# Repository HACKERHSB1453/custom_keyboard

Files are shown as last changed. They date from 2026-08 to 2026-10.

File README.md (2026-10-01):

# my-kkeb

A 113-key modular mechanical keyboard, split into 5 boards that connect with magnetic pogo pins. It is designed in KiCad (PCB) and Fusion (case) for Hack Club's KEEB program.

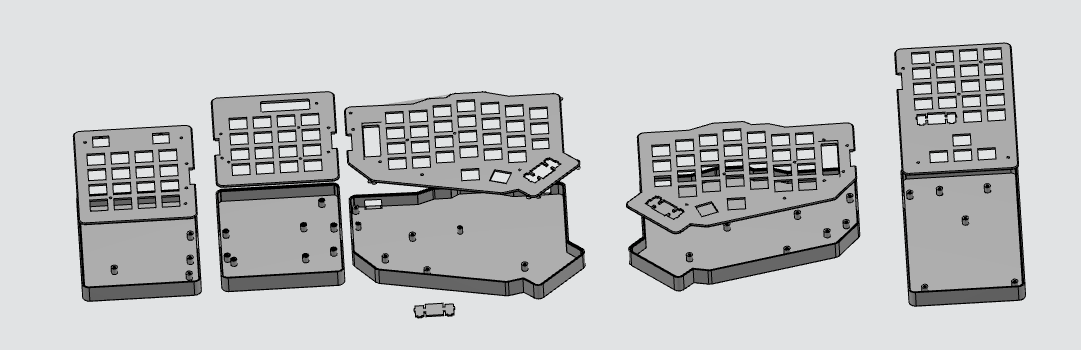
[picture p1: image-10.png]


## Why I built it
I build this because I was interested in split keyboard. I really like how they look but I dont like how they sacrifice a lot of keys and thats makes them difficult to use for some things. So I had the idea to make a modular split keyboard. 
## How it works
The way it works it pretty simple. A pi pico powers it all. I used mcp23017 chips so I could get enough pins for all the matrix rows and colums from just transfering 4 pins thought the modules.
## Repository layout

```
my-kkeb/                 KiCad project (schematics + PCB)
  CUSTOM.pretty/         custom footprints (pogo connector, hot-swap socket, USB-C)
  export/fab/            Gerber zips, one per board, ready for JLCPCB
case/
  <Module>/Case_*.step   case for each module (one body per file for printing)
  <Module>/Plate_*.step  switch plate for each module
  my-kkeb-case-assembly.step   everything together, for viewing only
```

## Building it

1. **PCBs:** upload each zip from `my-kkeb/export/fab/` to JLCPCB as a separate order (5 boards).
2. **Case:** print the `Case_*` and `Plate_*` files from `case/`. I plan to use JLC3DP in black resin.
3. **Parts:** see `bom.csv`
4. **Firmware:** not done yet

## What I learned
I learned a lot of stuff. I learn a lot about how keyboard work. What I think that is the most valuable thing about what I learned is the knowladge about PCBs, I knew some stuff but I have never tried to actually make a PCB before. And it was actually harder than I thought for some things. But overall I enjoyed a lot doing everything. Making the case was definetely harder than doing the PCB, because I didnt really know how to make the it at first. I tried using FreeCad at first since fusion wasnt in linux, and I didnt liked onshape. But I ended up intalling fusion in my windows and Did 95% of they case there and a did some changed on freecad late on.

## Build journal

**Total: 80 hours**

| Date | Hours | What I worked on |
|---|---|---|
| August 3 | 1 h | Research |
| August 4 | – | GitHub repo |
| August 14 | 2 h 50 min | Planning and first 3D model |
| August 15 | 8 h 40 min | Main model, planning, OLED, pogo pins, MCP23017 |
| August 16 | 3 h | PCB |
| August 17 | 3 h 30 min | PCB |
| August 18 | 2 h | Model changes, PCB |
| August 19 | 9 h | Schematic, ERC |
| August 20 | 7 h | PCB placement |
| August 21 | 16 h | PCB placement and wiring |
| August 23 | 4 h | Wiring |
| August 28 | 6 h | Case |
| September 13 | 7 h | Case, rewiring |
| September 20 | 3 h | Case |
| September 25 | 7 h | Case |

### August 3 (1 h)
I have been searching about how keayboards work. And how matrix system works. Spend a total of 1 hour investigating and watching videos about how to keyboards work and how to create one. Here are the links:
- https://www.youtube.com/watch?v=8WXpGTIbxlQ
- https://www.youtube.com/watch?v=7LyziNdFlew
- https://www.youtube.com/watch?v=h-NM1xSSzHQ

### August 4
I created the github repo.

### August 14 (2 h 50 min)
- **2:10AM-3AM:** Planning my keyboard.
- **10PM-12AM:** I kept planning and making a 3D model to get an idea about how the keyboard should look like.

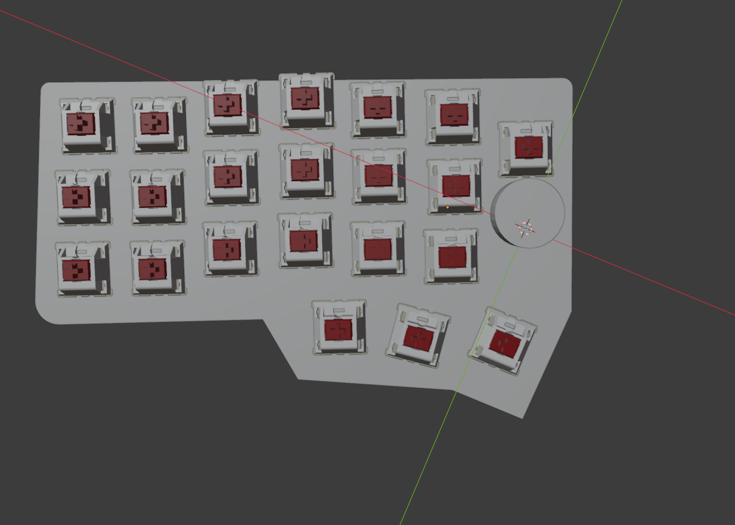
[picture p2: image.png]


### August 15 (8 h 40 min)
- **12AM-3AM:** I finished the main model.

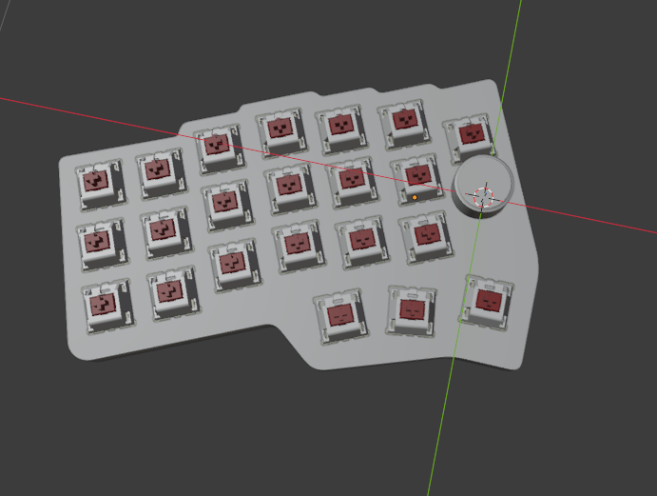
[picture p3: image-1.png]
  
- **3AM-4:40AM:** I tought that I could add more things so I made the keyboard bigger. And also added attachable parts.

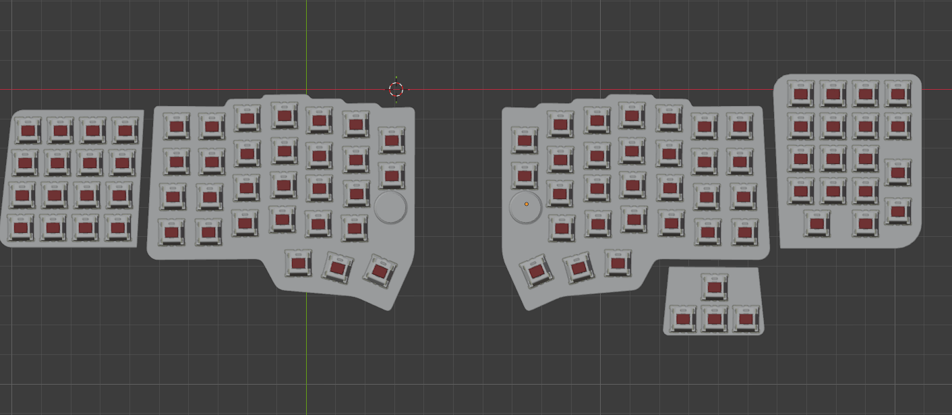
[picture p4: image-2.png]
  
- **4:40AM-6AM:** I planned where everything will go. Searched about how to make the keyboard hotswappable. I had a problem and it is that the keyboard has 96 keys and 2 knobs. The pi pico doesnt have enough pins. I had two main options, use 2 pi picos or use a another chip. But after inverstigating I found ot a way to make it work with a single pi pico.
- **2PM-4PM:** I added an oled screen, installed kicad. And also searched about ways to connect the keyboard with magnets. I found out about pogo pins. And I decided using them.
- **11:20PM-12AM:** I searched about encoreds and searched about how a MCP23017 works and how to use it. I also watched this video about it

### August 16 (3 h)
- **12:20AM-1:50AM:** I created the kicad project and started adding the base thing like the swithes and the pi pico
- **8PM-11PM:** I started designing the pcb.
  - **8:15PM-9PM:** At this point i had the matrix of the right and left part, but it wasnt wired yet.

### August 17 (3 h 30 min)
- **12:30AM-1:40AM:** kept drawing the switch matrix: D30-D58 and their switches
- **3:20AM-3:50AM:** moved the whole matrix out of the main sheet into its own sheet called `left_part` and started using hierarchical schematic since it was for my case. I couldnt find much info online, but I managed to make it work
- **7:30PM-11PM:** I continued with the PCB, I accidentally forgot to save the right part the day before and had to redo that. I also started organizsing thingsa and connect the two main parts. I also search about mousebites. And I decided to use it since the keybaord will be split in multiple parts.

### August 18 (2 h)
- **4AM-4:10AM:** split `left_part` into two sheets, **Left** and **Right** (60 symbols each), and made an empty numpad sheet
- **2:30PM-3:30PM:** I made some changes to the keyboard model.

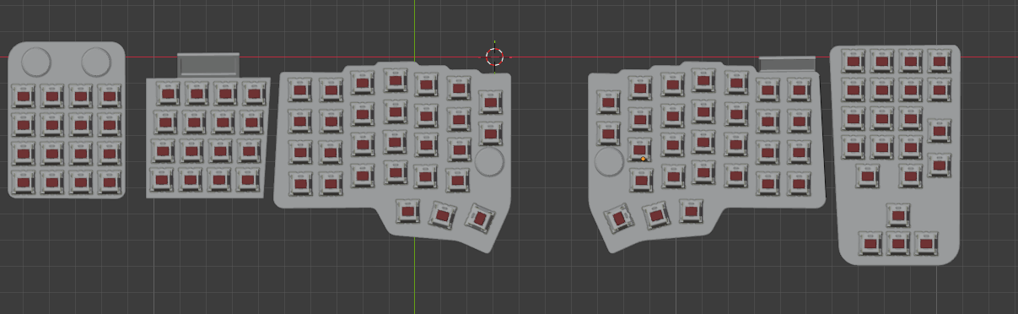
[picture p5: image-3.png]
  
- **3PM-3:50PM:** filled the **Numpad** sheet: switches, diodes D59-D80 and its connector J3. Added SW2 to the Left sheet
- **11PM-12AM:** I continued with the pcb

### August 19 (9 h)
- **12AM-3AM:** I kept doing the pcb, and finished the connections. I tried to use schematic hiererchy to organize it all. I hope I didnt mess it up. In this period I basically added the Macro pad and the git pad. Here are some photos:
  - **12AM-1AM:** made the **Macro_pad** sheet (diodes D81-D96, connectors J5, J7, J8) and an empty Git_pad sheet
  - **2:25AM-3AM:** filled the **Git_pad** sheet (diodes D97-D112, connector J9)

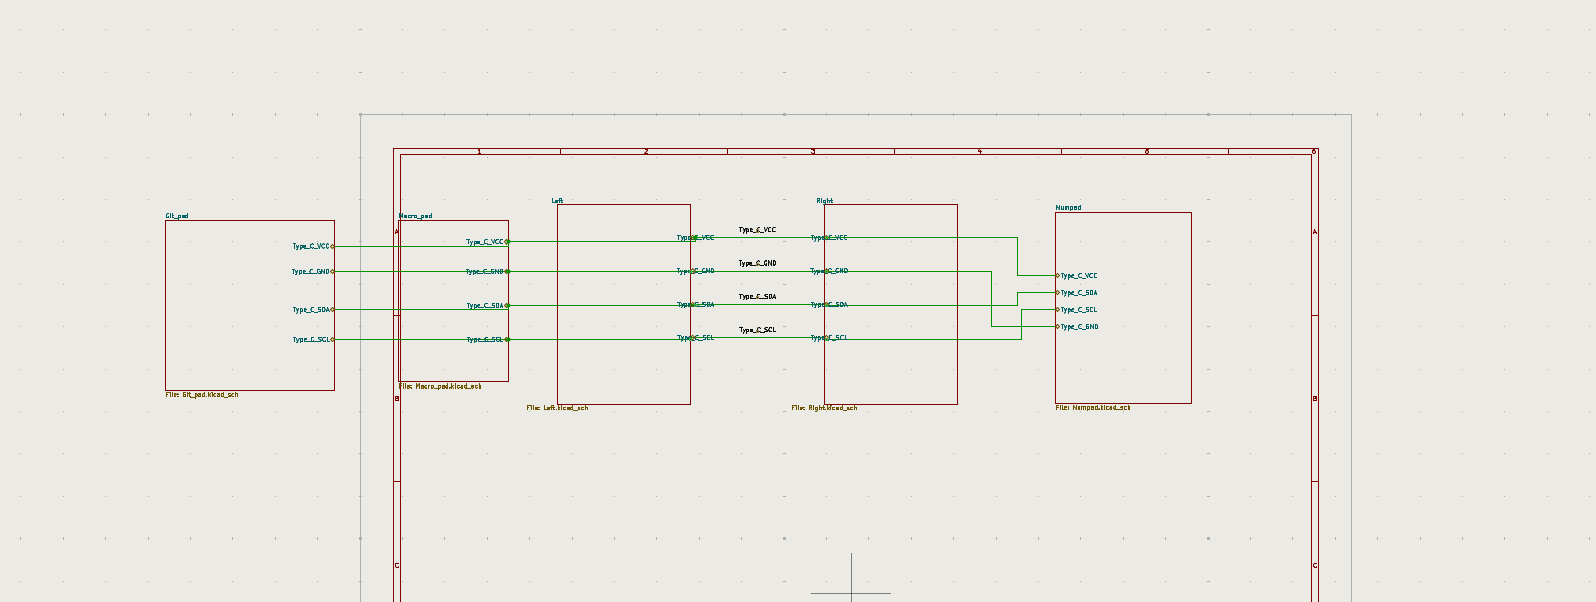
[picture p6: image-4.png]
  
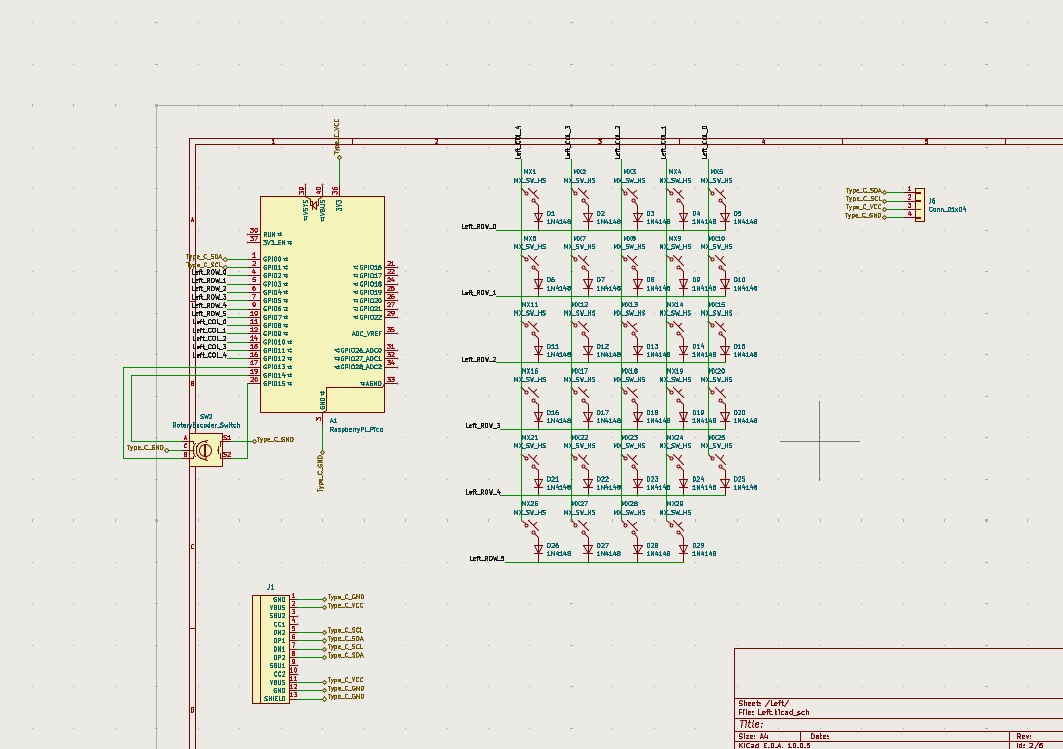
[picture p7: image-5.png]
  
- **3AM-7AM:** I fixed all the errors that didnt let me start the design of the PCB
  - **4:45AM-6:35AM:** first time the schematic was sent to the PCB editor: **247 footprints** appeared on the board. Replaced the old J1/J2 connectors with the two USB-C ports (J5 and J11)
- **10PM-12AM:** I run the ERC and got 74 errors. And I spend the time fixing them.
  - **11PM-11:40PM:** added labels on the Git_pad, Macro_pad, Numpad and Right sheets (the ERC fixing)

### August 20 (7 h)
- **12AM-5AM:** I started designing the PCB completed positioning the two main parts of the keybaord and also added the diodes to the left half. Here is a photo:
  - **12:45AM-4:50AM:** placed all 112 switches and the first 29 diodes on the Left board, and moved 31 parts to the back side. Removed an extra connector (J10)

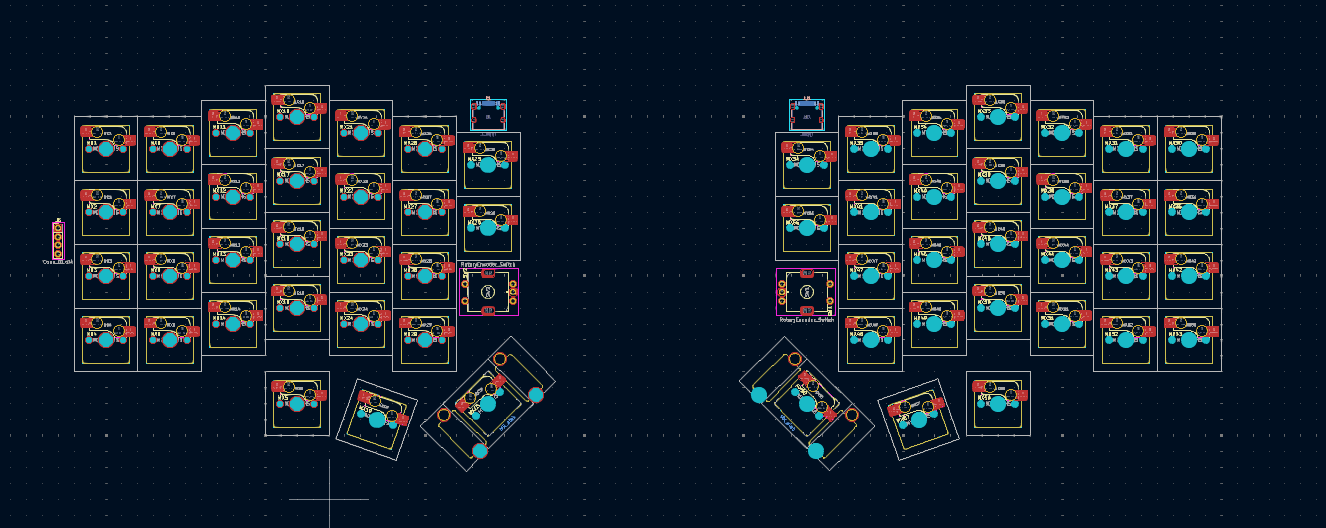
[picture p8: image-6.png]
  
- **10PM-12AM:** I continued with the PCB placement
  - **11PM-2:40AM:** placed all 112 diodes, the rest of the switches, the chips and the connectors (246 parts moved). Added the 113th key (MX113 and D113) to the Numpad

*(Postdata: I messed up really bad here, because I thought that the kailh sockets had to go on the front of the plate, I had to fix that late one)*

### August 21 (16 h)
- **12AM-5AM:** I finished the placement of the compenents in the PCB
- **10PM-12AM:** I continued started wiring the components
- **12AM-9AM:** I finished the wiring of the right part, left part. And the numpad.
  - **4:20AM-5:50AM:** first wiring: 553 track pieces and 87 vias
  - **7:15AM-9AM:** kept wigin and got up to **1,987 track pieces and 247 vias**

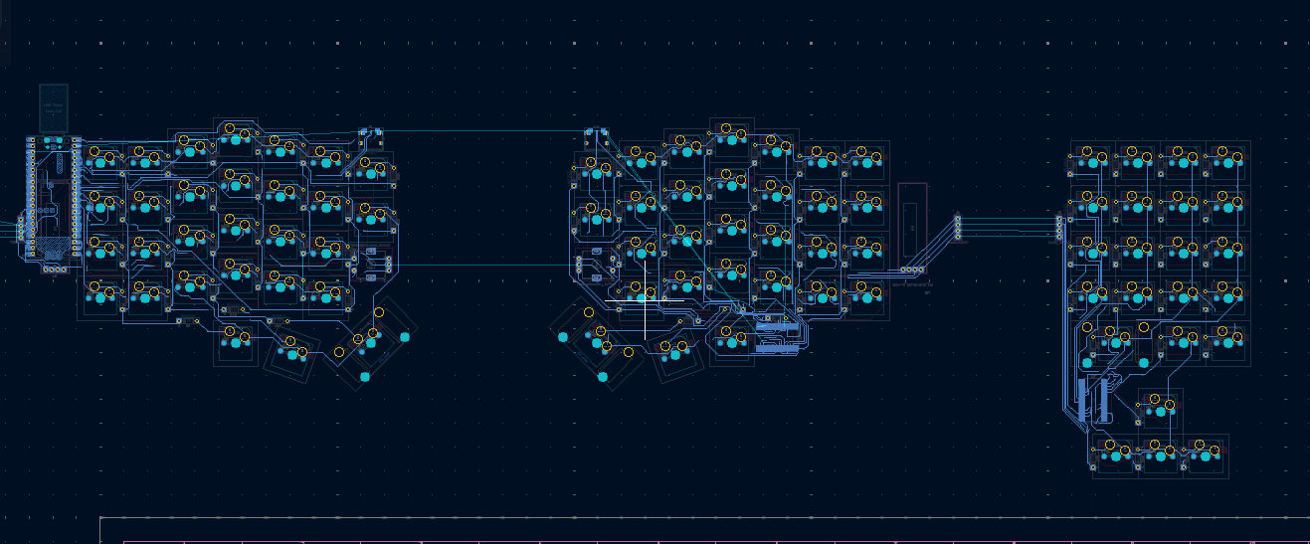
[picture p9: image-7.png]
  

### August 23 (4 h)
- **12AM-4AM:** I finished wiring all the keybaord.
  - **1:20AM-5AM:** kept wiring and got from 1,987 to 2,514 track pieces, 324 vias
- **7:45PM-8:10PM:** restored a backup from KiCad's history, then kept wiring
- **9:45PM-10:30PM:** more wiring, up to **2,798 track pieces and 361 vias**

### August 24
- **2:30AM-3:30AM:** I added some ressistors and capacitators.

### August 28 (6 h)
- **12AM-6AM:** I started designing the case

### August 31
- **1:20AM-6:30AM:** I hadded mountholes to the pcb. Run DRC again, got a bunch of problems I solved the,

### September 13 (7 h)
- **12AM-2AM:** I kept designing the case
- **2AM-7AM:** I noticed that I had the kailh hotswap sockets in the wrong side of the board, so I had to basically rewire everything.

### September 20 (3 h)
- **3PM-6PM:** I kept designing everything, and finished the numpad.

### September 25 (7 h)
- **11AM-6PM:** I finished the full case, and seperated it into different files. Here are some photos:

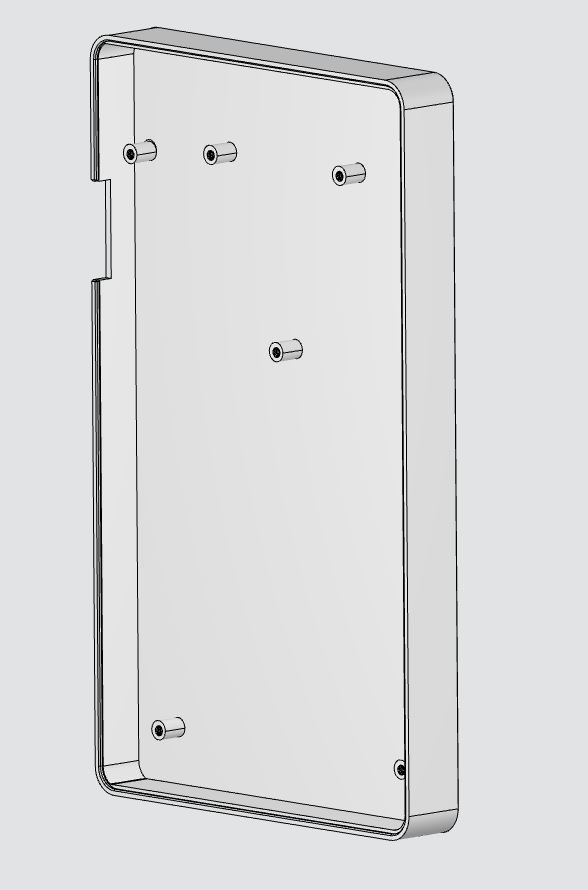
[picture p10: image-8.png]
  
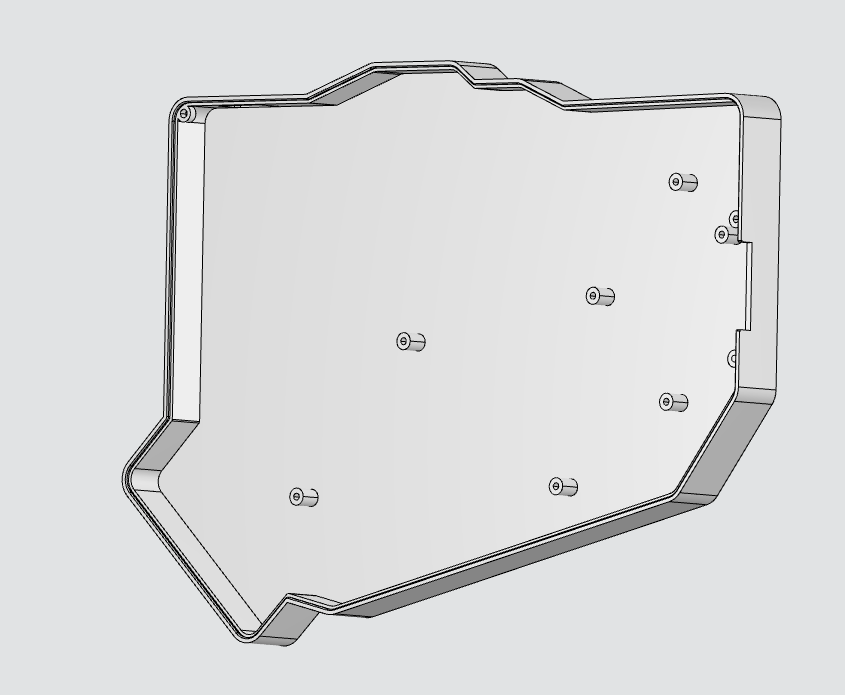
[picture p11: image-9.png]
  
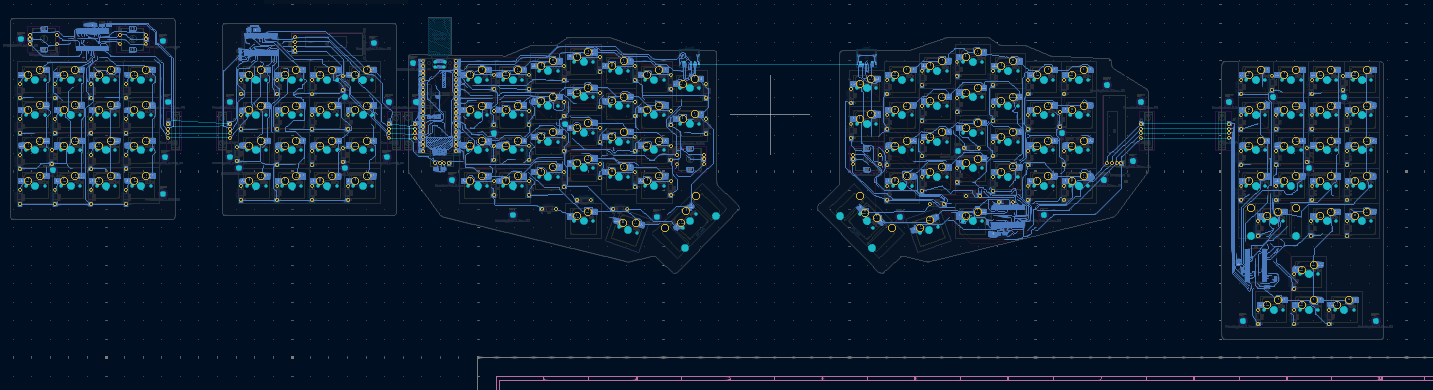
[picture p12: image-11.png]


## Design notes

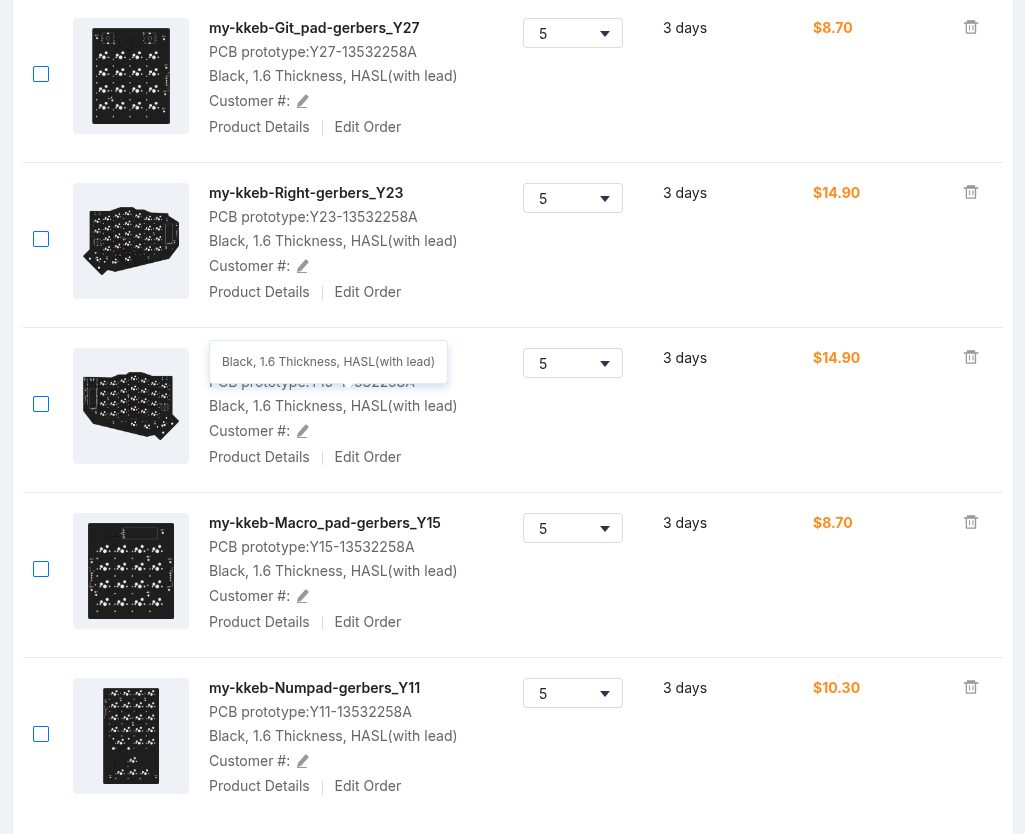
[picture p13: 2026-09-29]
image copy.png

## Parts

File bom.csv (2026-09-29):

Item | Qty | Designators | Description | Part number / spec | Footprint / file | Supplier | Link | Unit price (USD) | Total (USD) | Notes
--- PCBs ---
PCB - Left | 5 |  | 2-layer FR-4, 1.6 mm, 127.05 x 178.22 mm | HASL (lead-free) finish | my-kkeb/export/fab/my-kkeb-Left-gerbers.zip | JLCPCB |  |  | incl. in JLC order | Minimum order is 5; 1 is used
PCB - Right | 5 |  | 2-layer FR-4, 1.6 mm, 127.05 x 178.22 mm | HASL (lead-free) finish | my-kkeb/export/fab/my-kkeb-Right-gerbers.zip | JLCPCB |  |  | incl. in JLC order | Minimum order is 5; 1 is used
PCB - Macro_pad | 5 |  | 2-layer FR-4, 1.6 mm, 103.74 x 93.73 mm | HASL (lead-free) finish | my-kkeb/export/fab/my-kkeb-Macro_pad-gerbers.zip | JLCPCB |  |  | incl. in JLC order | Minimum order is 5; 1 is used
PCB - Git_pad | 5 |  | 2-layer FR-4, 1.6 mm, 108.61 x 88.76 mm | HASL (lead-free) finish | my-kkeb/export/fab/my-kkeb-Git_pad-gerbers.zip | JLCPCB |  |  | incl. in JLC order | Minimum order is 5; 1 is used
PCB - Numpad | 5 |  | 2-layer FR-4, 1.6 mm, 149.74 x 87.07 mm | HASL (lead-free) finish | my-kkeb/export/fab/my-kkeb-Numpad-gerbers.zip | JLCPCB |  |  | incl. in JLC order | Minimum order is 5; 1 is used
--- 3D printed case ---
Case - Left | 1 |  | Case | JLC Black Resin (SLA), with sanding | case/Left/Case_Left.step | JLC3DP |  |  | incl. in JLC order
Plate - Left | 1 |  | Switch plate, 2 mm (1.5 mm at the switches) | JLC Black Resin (SLA) | case/Left/Plate_Left.step | JLC3DP |  |  | incl. in JLC order | Sanding optional
Case - Right | 1 |  | Case | JLC Black Resin (SLA), with sanding | case/Right/Case_Right.step | JLC3DP |  |  | incl. in JLC order
Plate - Right | 1 |  | Switch plate, 2 mm (1.5 mm at the switches) | JLC Black Resin (SLA) | case/Right/Plate_Right.step | JLC3DP |  |  | incl. in JLC order | Sanding optional
Case - Macro_pad | 1 |  | Case | JLC Black Resin (SLA), with sanding | case/Macro_pad/Case_Macro_pad.step | JLC3DP |  |  | incl. in JLC order
Plate - Macro_pad | 1 |  | Switch plate, 2 mm (1.5 mm at the switches) | JLC Black Resin (SLA) | case/Macro_pad/Plate_Macro_pad.step | JLC3DP |  |  | incl. in JLC order | Sanding optional
Case - Git_pad | 1 |  | Case | JLC Black Resin (SLA), with sanding | case/Git_pad/Case_Git_pad.step | JLC3DP |  |  | incl. in JLC order
Plate - Git_pad | 1 |  | Switch plate, 2 mm (1.5 mm at the switches) | JLC Black Resin (SLA) | case/Git_pad/Plate_Git_pad.step | JLC3DP |  |  | incl. in JLC order | Sanding optional
Case - Numpad | 1 |  | Case | JLC Black Resin (SLA), with sanding | case/Numpad/Case_Numpad.step | JLC3DP |  |  | incl. in JLC order
Plate - Numpad | 1 |  | Switch plate, 2 mm (1.5 mm at the switches) | JLC Black Resin (SLA) | case/Numpad/Plate_Numpad.step | JLC3DP |  |  | incl. in JLC order | Sanding optional
JLC order (PCBs + cases + plates) | 1 |  | Final checkout price: all 5 PCB designs and all printed parts above, incl. shipping and VAT |  |  | JLCPCB / JLC3DP |  | 198.00 | 198.00
--- Electronics (from the schematic) ---
Raspberry Pi Pico | 1 | A1 | Microcontroller board | Raspberry Pi Pico SC0915 (official, micro-USB, no headers) | Module:RaspberryPi_Pico_Common_Unspecified | TME |  |  | 4.85 | Solder flat by the castellated edges on the back of the Left board
I/O expander | 4 | U1-U4 | 16-bit I2C I/O expander | MCP23017-E/SO (SOIC-28) | Package_SO:SOIC-28W_7.5x17.9mm_P1.27mm | TME |  |  | 7.44
Diode | 115 | D1-D113 | Switching diode, through-hole | 1N4148 (DO-35), TME 1N4148-DIO | Diode_THT:D_DO-35_SOD27_P7.62mm_Horizontal | TME |  |  | 3.78
Hot-swap socket | 120 | MX1-MX113 | MX hot-swap socket | Kailh CPG151101S11 (110 pcs + 10 pcs) | CUSTOM:SW_MX_HS_CPG151101S11_1u_PinSwap | AliExpress |  |  | 14.51
Resistor 2.2k | 10 | R1, R2 | I2C pull-up | 2.2 kOhm 1%, 0603, Walsin WR06X2201FTL | Resistor_SMD:R_0603_1608Metric | TME |  |  | 0.08 | 2 needed
Resistor 100 | 10 | R3, R4, R7-R12 | I2C series resistor | 100 Ohm 5%, 0603, Walsin WR06X101JTL | Resistor_SMD:R_0603_1608Metric | TME |  |  | 0.11 | 8 needed
Capacitor 100nF | 4 | C1, C3, C5, C7 | Decoupling | 100 nF 50 V X7R, 0603, Walsin 0603B104K500CT | Capacitor_SMD:C_0603_1608Metric | TME |  |  | 0.33
Capacitor 10uF | 4 | C2, C4, C6, C8 | Bulk decoupling | 10 uF 25 V X5R, 0805, Samsung CL21A106KAYNNNE | Capacitor_SMD:C_0805_2012Metric | TME |  |  | 1.17
USB-C receptacle | 5 | J5, J11 | Link between the two halves (I2C + 3.3 V, not real USB) | USB-C 16-pin SMD receptacle (TYPE-C-31-M-12 type), 5 pcs | CUSTOM:USB_C_Receptacle_HRO_TYPE-C-31-M-12_4Pin_Fixed | AliExpress |  |  | 1.81 | 2 needed. Link between the two halves (I2C + 3.3 V, not real USB)
Magnetic pogo connector | 3 pairs | J3, J4, J6, J7, J8, J9 | 4-pin magnetic pogo connector, 2.54 mm pitch, right angle, with ears | 4-pin magnetic pogo, 2.54 mm, 'With Ear, Curved needle', male + female | CUSTOM:PogoMag_1x04_P2.54mm_RightAngle(_Mirror) | AliExpress |  | 6.18 | paid by me | Paid with my own money (order had import customs), not included in the grant total. J9, J8, J4 are one gender; J7, J6, J3 the other
Rotary encoder | 1 pack | SW1-SW4 | Rotary encoder with push switch | EC11 with push switch, 20 mm half (D) shaft | PCM_marbastlib-various:ROT_Alps_EC11E-Switch | AliExpress |  |  | 5.77 | 4 needed
OLED display | 3 | U5, U6, U7 | 0.91 in 128x32 OLED, SSD1306, I2C | APKLVSR 0.91 in 128x32 I2C SSD1306, 3-pack | Display:ER_OLEDM0.91_1x-I2C | Amazon |  |  | 17.07 | Pin order must be GND-VCC-SCL-SDA
Stabilizer 2u | 1 set | S1, S3, S5 | 2u stabilizer, PCB-mount | ECSiNG board-mount (PCB-mount) stabilizers, 7 x 2u + 1 x 6.25u | PCM_marbastlib-mx:STAB_MX_P_2u | Amazon |  |  | 8.30 | 3 x 2u needed
--- Keys ---
Switches | 120 |  | MX-style switches | Outemu Clicky Green, 3-pin (110 pcs + 10 pcs) |  | AliExpress |  |  | 21.07 | 113 needed
Keycaps 1u | 1 set |  | MX-stem keycaps, 1u | YMDK 127-key ZDA (XDA V2) PBT, blank black |  | Amazon |  |  | 28.60 | One set covers the 1u and 2u keys
Keycaps 2u | 3 |  | MX-stem keycaps, 2u | Included in the YMDK set |  | Amazon |  |  | incl. in keycap set
Encoder knobs | 4 |  | Knobs for EC11 encoders | Must match the encoder shaft (D-shaft or knurled) |  |  |  |  | not bought for now | Not part of this order
--- Hardware ---
Screw M2x6 | 1 kit |  | PCB to case (PCB-only positions) | 600 pcs M2 hex button head screw kit (incl. M2x6 and M2x10) |  | Amazon |  |  | 10.24 | Threaded holes are 5.5 mm deep: M2x6 for PCB-only, M2x10 for plate + PCB. Never M2x8+ PCB-only or M2x12
Screw M2x10 | 35 |  | Plate + PCB to case | Included in the M2 screw kit |  | Amazon |  |  | incl. in screw kit | Do NOT use M2x12 (reaches the bottom of the hole)
Spacer M2x3 | 0 |  | Between plate and PCB, one per M2x10 screw | Not bought |  |  |  |  | not bought | Optional; using PCB-only screws instead
--- Cables ---
USB-C to USB-C cable | 1 |  | Short cable between the two halves (J5-J11) | USB-C to USB-C, short |  | Own |  |  | already owned | Never plug J5/J11 into a computer: they carry I2C, not USB
USB cable | 1 |  | Pico to computer | Micro-USB data cable (official Pico is micro-USB) |  | Own |  |  | already owned
--- Shipping ---
Shipping - JLCPCB | 1 |  | PCB shipping |  |  | JLCPCB |  |  | incl. in JLC order
Shipping - JLC3DP | 1 |  | 3D print shipping |  |  | JLC3DP |  |  | incl. in JLC order
Import VAT - JLC order | 1 |  | Spanish VAT (21%) on the JLC order, paid at checkout (DDP) |  |  | JLCPCB / JLC3DP |  |  | incl. in JLC order | Already inside the JLC order total; VAT only, customs duty is $0
Shipping - TME | 1 |  | Shipping |  |  | TME |  |  | 15.02
Shipping - AliExpress (pogo order) | 1 |  | Shipping |  |  | AliExpress |  | 2.64 | paid by me | Pogo order paid with my own money, not included in the grant total
Shipping - AliExpress (other orders) | 1 |  | Shipping |  |  | AliExpress |  |  | free
Shipping - Amazon | 1 |  | Shipping |  |  | Amazon |  |  | free
--- Total ---
TOTAL |  |  |  |  |  |  |  |  | 338.15 | Grant limit $400 (80 h x $5). Prices converted at 1 EUR = 1.139 USD

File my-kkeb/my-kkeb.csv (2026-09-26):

Reference | Qty | Value | DNP | Exclude from BOM | Exclude from Board | Exclude from Simulation | Exclude from Position Files | Footprint | Datasheet
A1 | 1 | RaspberryPi_Pico |  |  |  |  | ${EXCLUDE_FROM_POS_FILES} | Module:RaspberryPi_Pico_Common_Unspecified | https://datasheets.raspberrypi.com/pico/pico-datasheet.pdf
C1,C3,C5,C7 | 4 | 100nF |  |  |  |  | ${EXCLUDE_FROM_POS_FILES} | Capacitor_SMD:C_0603_1608Metric
C2,C4,C6,C8 | 4 | 10uF |  |  |  |  | ${EXCLUDE_FROM_POS_FILES} | Capacitor_SMD:C_0805_2012Metric
D1,D2,D3,D4,D5,D6,D7,D8,D9,D10,D11,D12,D13,D14,D15,D16,D17,D18,D19,D20,D21,D22,D23,D24,D25,D26,D27,D28,D29,D30,D31,D32,D33,D34,D35,D36,D37,D38,D39,D40,D41,D42,D43,D44,D45,D46,D47,D48,D49,D50,D51,D52,D53,D54,D55,D56,D57,D58,D59,D60,D61,D62,D63,D64,D65,D66,D67,D68,D69,D70,D71,D72,D73,D74,D75,D76,D77,D78,D79,D80,D81,D82,D83,D84,D85,D86,D87,D88,D89,D90,D91,D92,D93,D94,D95,D96,D97,D98,D99,D100,D101,D102,D103,D104,D105,D106,D107,D108,D109,D110,D111,D112,D113 | 113 | 1N4148 |  |  |  |  | ${EXCLUDE_FROM_POS_FILES} | Diode_THT:D_DO-35_SOD27_P7.62mm_Horizontal | https://assets.nexperia.com/documents/data-sheet/1N4148_1N4448.pdf
J3,J4,J6,J7,J8,J9 | 6 | Conn_01x04 |  |  |  |  | ${EXCLUDE_FROM_POS_FILES} | CUSTOM:PogoMag_1x04_P2.54mm_RightAngle
J5 | 1 | Type_C |  |  |  |  | ${EXCLUDE_FROM_POS_FILES} | CUSTOM:USB_C_Receptacle_HRO_TYPE-C-31-M-12_4Pin_Fixed
J11 | 1 | TypeC |  |  |  |  | ${EXCLUDE_FROM_POS_FILES} | CUSTOM:USB_C_Receptacle_HRO_TYPE-C-31-M-12_4Pin_Fixed
MX1,MX2,MX3,MX4,MX5,MX6,MX7,MX8,MX9,MX10,MX11,MX12,MX13,MX14,MX15,MX16,MX17,MX18,MX19,MX20,MX21,MX22,MX23,MX24,MX25,MX26,MX27,MX28,MX29,MX30,MX31,MX32,MX33,MX34,MX35,MX36,MX37,MX38,MX39,MX40,MX41,MX42,MX43,MX44,MX45,MX46,MX47,MX48,MX49,MX50,MX51,MX52,MX53,MX54,MX55,MX56,MX57,MX58,MX59,MX60,MX61,MX62,MX63,MX64,MX65,MX66,MX67,MX68,MX69,MX70,MX71,MX72,MX73,MX74,MX75,MX76,MX77,MX78,MX79,MX80,MX81,MX82,MX83,MX84,MX85,MX86,MX87,MX88,MX89,MX90,MX91,MX92,MX93,MX94,MX95,MX96,MX97,MX98,MX99,MX100,MX101,MX102,MX103,MX104,MX105,MX106,MX107,MX108,MX109,MX110,MX111,MX112,MX113 | 113 | MX_SW_HS |  |  |  |  | ${EXCLUDE_FROM_POS_FILES} | CUSTOM:SW_MX_HS_CPG151101S11_1u_PinSwap
R1,R2 | 2 | 2.2k |  |  |  |  | ${EXCLUDE_FROM_POS_FILES} | Resistor_SMD:R_0603_1608Metric
R3,R4,R7,R8,R9,R10,R11,R12 | 8 | 100 |  |  |  |  | ${EXCLUDE_FROM_POS_FILES} | Resistor_SMD:R_0603_1608Metric
S1,S3,S5 | 3 | MX_stab |  |  |  |  | ${EXCLUDE_FROM_POS_FILES} | PCM_marbastlib-mx:STAB_MX_P_2u
SW1,SW2,SW3,SW4 | 4 | RotaryEncoder_Switch |  |  |  |  | ${EXCLUDE_FROM_POS_FILES} | PCM_marbastlib-various:ROT_Alps_EC11E-Switch
U1,U2,U3,U4 | 4 | MCP23017x-x-SO |  |  |  |  | ${EXCLUDE_FROM_POS_FILES} | Package_SO:SOIC-28W_7.5x17.9mm_P1.27mm | https://ww1.microchip.com/downloads/aemDocuments/documents/APID/ProductDocuments/DataSheets/MCP23017-Data-Sheet-DS20001952.pdf
U5,U6,U7 | 3 | ER_OLEDM0.91_1x-I2C |  |  |  |  | ${EXCLUDE_FROM_POS_FILES} | Display:ER_OLEDM0.91_1x-I2C | https://www.buydisplay.com/download/manual/ER-OLEDM0.91-1_Datasheet.pdf

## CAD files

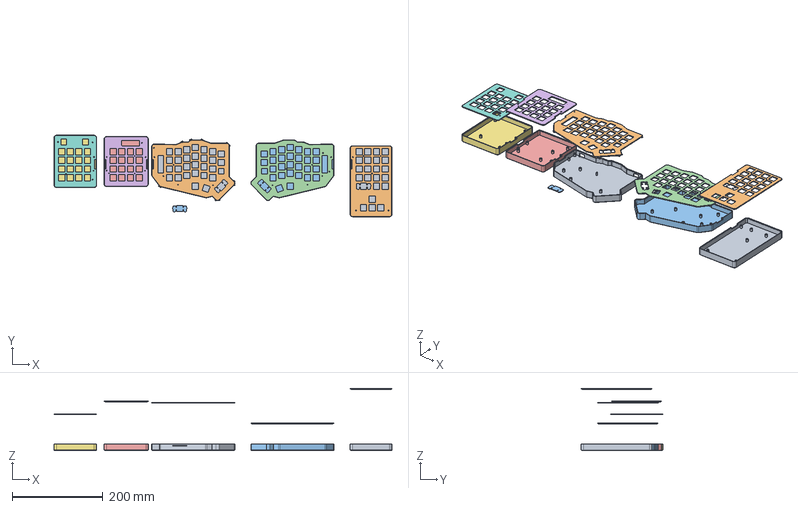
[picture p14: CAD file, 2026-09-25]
case/my-kkeb-case-assembly.step
746.3 x 180.1 x 137.0 mm
Case_Left
Plate_Left
Case_Right
Plate_Right
Case_Macro_pad
Plate_Macro_pad
Case_Git_pad
Plate_Git_pad
Case_Numpad
Plate_Numpad
Case_small_part

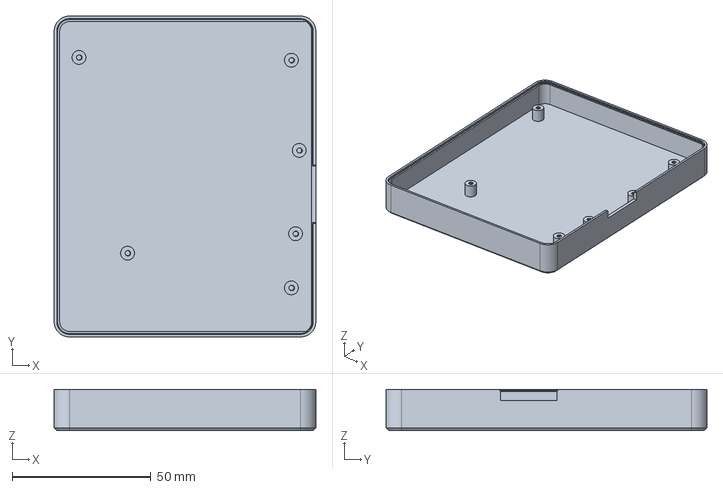
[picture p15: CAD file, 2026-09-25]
case/Git_pad/Case_Git_pad.step
94.3 x 115.6 x 14.8 mm

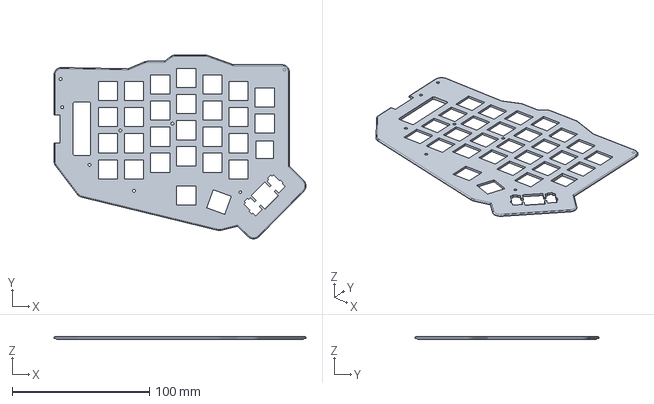
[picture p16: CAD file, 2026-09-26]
case/Left/Plate_Left.step
183.7 x 134.0 x 2.00 mm

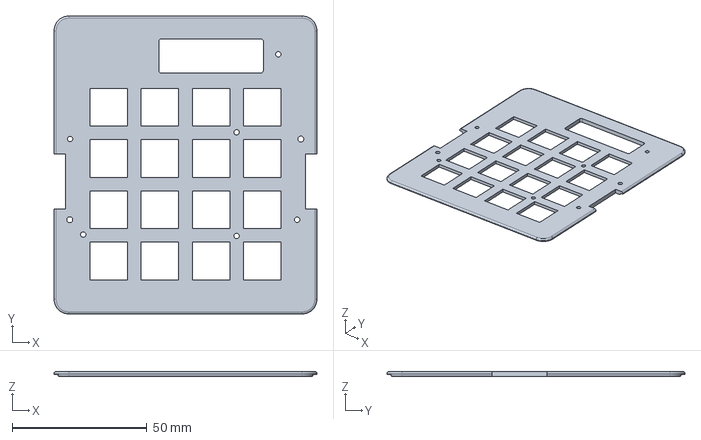
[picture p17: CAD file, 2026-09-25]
case/Macro_pad/Plate_Macro_pad.step
97.7 x 110.7 x 2.00 mm

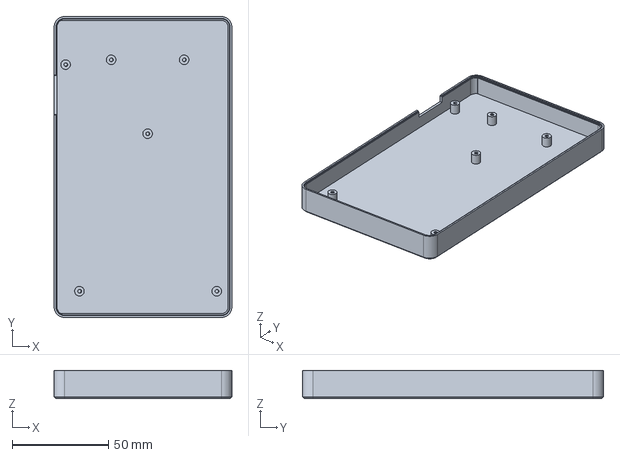
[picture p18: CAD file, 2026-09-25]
case/Numpad/Case_Numpad.step
92.6 x 156.7 x 14.8 mm

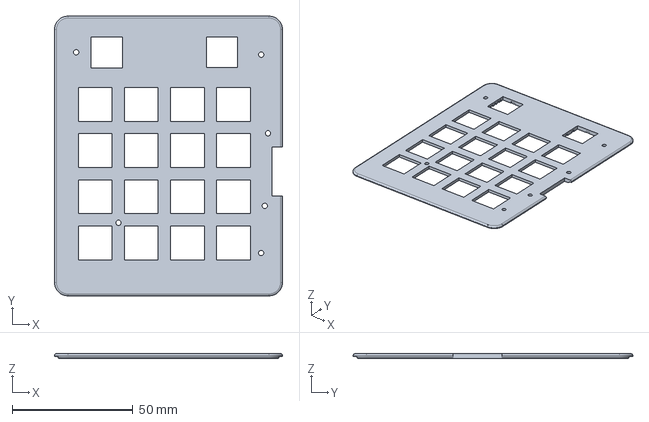
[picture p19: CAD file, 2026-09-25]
case/Git_pad/Plate_Git_pad.step
94.3 x 115.6 x 2.00 mm

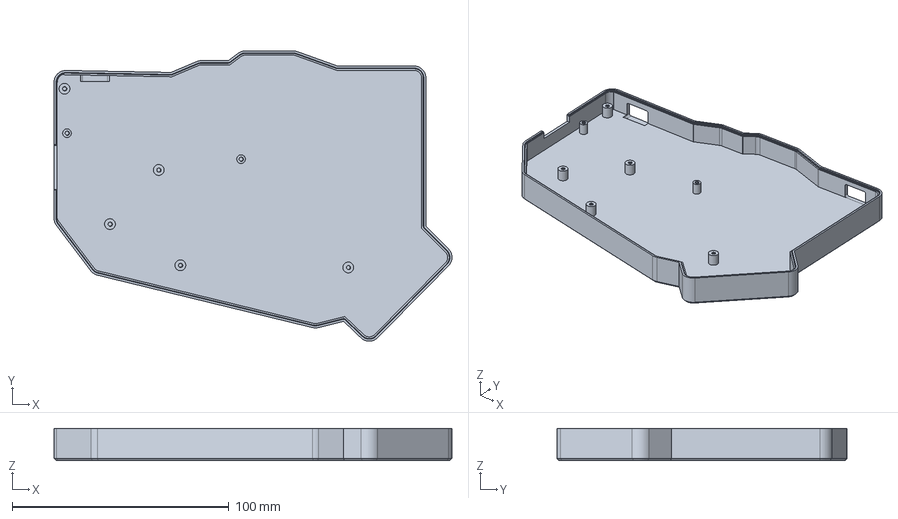
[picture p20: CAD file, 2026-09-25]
case/Left/Case_Left.step
183.7 x 134.0 x 14.8 mm

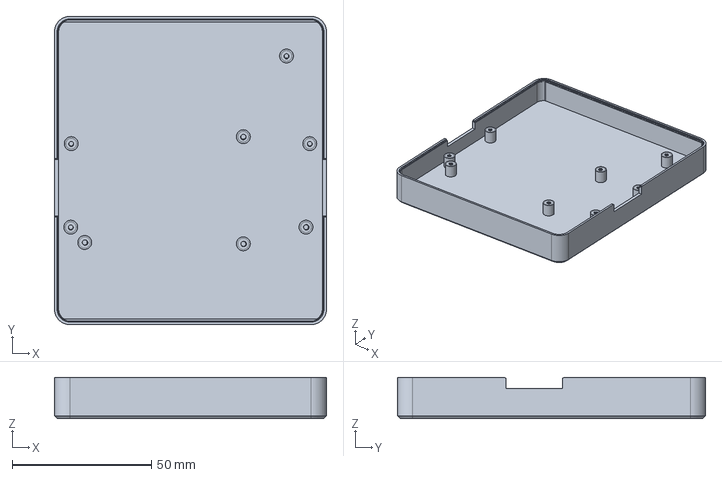
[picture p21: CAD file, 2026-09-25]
case/Macro_pad/Case_Macro_pad.step
97.7 x 110.7 x 14.8 mm

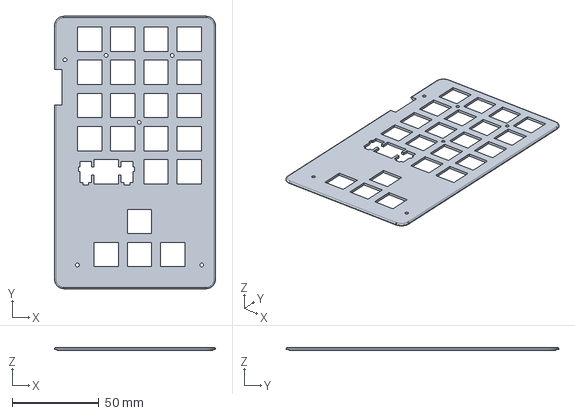
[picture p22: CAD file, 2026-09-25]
case/Numpad/Plate_Numpad.step
92.6 x 156.7 x 2.00 mm

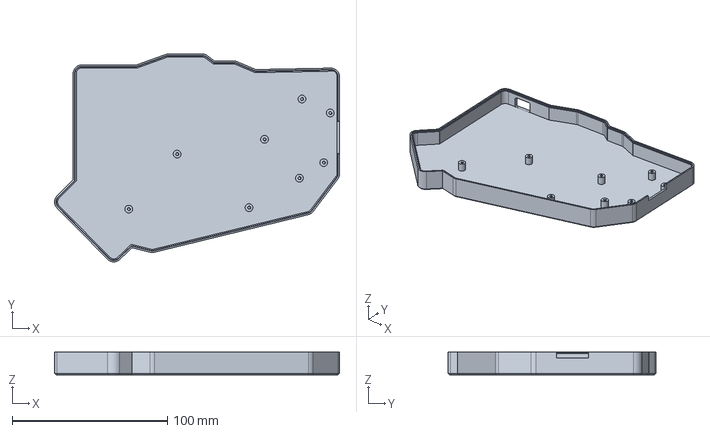
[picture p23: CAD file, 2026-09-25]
case/Right/Case_Right.step
183.7 x 134.0 x 14.8 mm

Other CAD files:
case/Right/Plate_Right.step

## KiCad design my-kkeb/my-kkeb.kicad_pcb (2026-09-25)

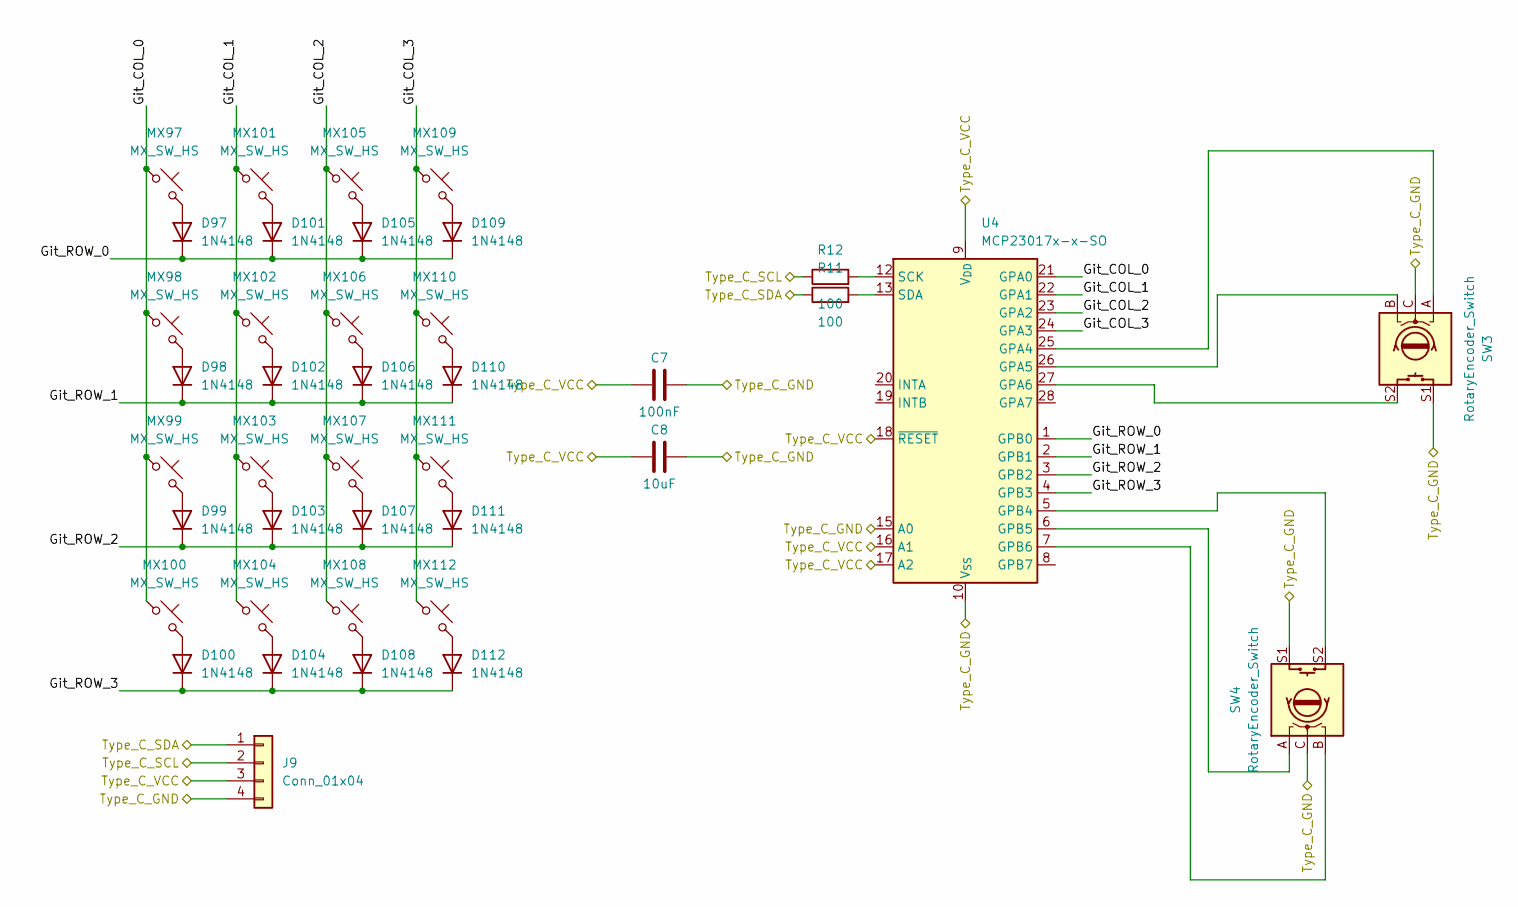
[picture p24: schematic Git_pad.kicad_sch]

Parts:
C7: 100nF; C_0603_1608Metric
C8: 10uF; C_0805_2012Metric
D97, D98, D99, D100, D101, D102, D103, D104, D105, D106, D107, D108, D109, D110, D111, D112: 1N4148; D_DO-35_SOD27_P7.62mm_Horizontal
J9: Conn_01x04; PogoMag_1x04_P2.54mm_RightAngle
MX97, MX98, MX99, MX100, MX101, MX102, MX103, MX104, MX105, MX106, MX107, MX108, MX109, MX110, MX111, MX112: MX_SW_HS; SW_MX_HS_CPG151101S11_1u_PinSwap
R11, R12: 100; R_0603_1608Metric
SW3, SW4: RotaryEncoder_Switch; ROT_Alps_EC11E-Switch
U4: MCP23017x-x-SO; SOIC-28W_7.5x17.9mm_P1.27mm

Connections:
/Git_pad/Git_COL_0: MX97.1 (2_2), MX98.1 (2_2), MX99.1 (2_2), MX100.1 (2_2), U4.21 (GPA0)
/Git_pad/Git_COL_1: MX101.1 (2_2), MX102.1 (2_2), MX103.1 (2_2), MX104.1 (2_2), U4.22 (GPA1)
/Git_pad/Git_COL_2: MX105.1 (2_2), MX106.1 (2_2), MX107.1 (2_2), MX108.1 (2_2), U4.23 (GPA2)
/Git_pad/Git_COL_3: MX109.1 (2_2), MX110.1 (2_2), MX111.1 (2_2), MX112.1 (2_2), U4.24 (GPA3)
/Git_pad/Git_ROW_0: D97.1 (K), D101.1 (K), D105.1 (K), D109.1 (K), U4.1 (GPB0)
/Git_pad/Git_ROW_1: D98.1 (K), D102.1 (K), D106.1 (K), D110.1 (K), U4.2 (GPB1)
/Git_pad/Git_ROW_2: D99.1 (K), D103.1 (K), D107.1 (K), D111.1 (K), U4.3 (GPB2)
/Git_pad/Git_ROW_3: D100.1 (K), D104.1 (K), D108.1 (K), D112.1 (K), U4.4 (GPB3)
/Git_pad/Type_C_GND: C7.2, C8.2, J9.4, SW3.C, SW3.S1, SW4.C, SW4.S1, U4.10 (V_{SS}), U4.15 (A0); also elsewhere on the board
/Git_pad/Type_C_SCL: J9.2, R12.1; also elsewhere on the board
/Git_pad/Type_C_SDA: J9.1, R11.1; also elsewhere on the board
/Git_pad/Type_C_VCC: C7.1, C8.1, J9.3, U4.9 (V_{DD}), U4.16 (A1), U4.17 (A2), U4.18 (~RESET); also elsewhere on the board
unnamed: D97.2 (A), MX97.2 (1_1)
unnamed: D98.2 (A), MX98.2 (1_1)
unnamed: D99.2 (A), MX99.2 (1_1)
unnamed: D100.2 (A), MX100.2 (1_1)
unnamed: D101.2 (A), MX101.2 (1_1)
unnamed: D102.2 (A), MX102.2 (1_1)
unnamed: D103.2 (A), MX103.2 (1_1)
unnamed: D104.2 (A), MX104.2 (1_1)
unnamed: D105.2 (A), MX105.2 (1_1)
unnamed: D106.2 (A), MX106.2 (1_1)
unnamed: D107.2 (A), MX107.2 (1_1)
unnamed: D108.2 (A), MX108.2 (1_1)
unnamed: D109.2 (A), MX109.2 (1_1)
unnamed: D110.2 (A), MX110.2 (1_1)
unnamed: D111.2 (A), MX111.2 (1_1)
unnamed: D112.2 (A), MX112.2 (1_1)
unnamed: SW3.A, U4.25 (GPA4)
unnamed: SW3.B, U4.26 (GPA5)
unnamed: SW3.S2, U4.27 (GPA6)
unnamed: SW4.S2, U4.5 (GPB4)
unnamed: SW4.A, U4.6 (GPB5)
unnamed: SW4.B, U4.7 (GPB6)
unnamed: R12.2, U4.12 (SCK)
unnamed: R11.2, U4.13 (SDA)

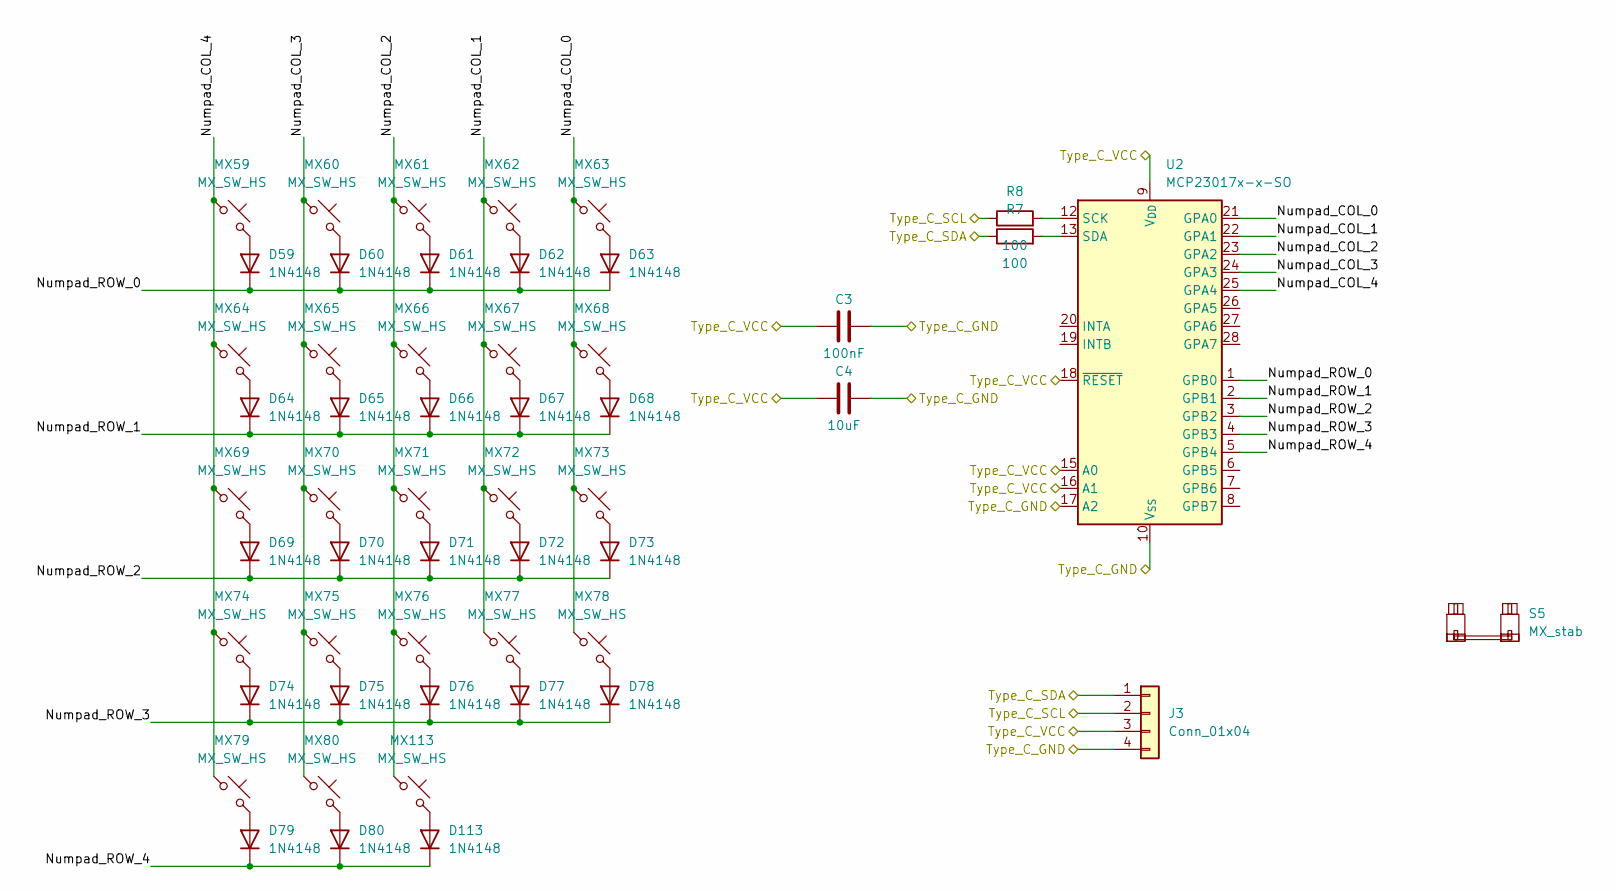
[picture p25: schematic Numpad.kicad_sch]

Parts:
C3: 100nF; C_0603_1608Metric
C4: 10uF; C_0805_2012Metric
D59, D60, D61, D62, D63, D64, D65, D66, D67, D68, D69, D70, D71, D72, D73, D74, D75, D76, D77, D78, D79, D80, D113: 1N4148; D_DO-35_SOD27_P7.62mm_Horizontal
J3: Conn_01x04; PogoMag_1x04_P2.54mm_RightAngle
MX59, MX60, MX61, MX62, MX63, MX64, MX65, MX66, MX67, MX68, MX69, MX70, MX71, MX72, MX73, MX74, MX75, MX76, MX77, MX78, MX79, MX80, MX113: MX_SW_HS; SW_MX_HS_CPG151101S11_1u_PinSwap
R7, R8: 100; R_0603_1608Metric
S5: MX_stab; STAB_MX_P_2u
U2: MCP23017x-x-SO; SOIC-28W_7.5x17.9mm_P1.27mm

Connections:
/Git_pad/Type_C_GND: C3.2, C4.2, J3.4, U2.10 (V_{SS}), U2.17 (A2); also elsewhere on the board
/Git_pad/Type_C_SCL: J3.2, R8.1; also elsewhere on the board
/Git_pad/Type_C_SDA: J3.1, R7.1; also elsewhere on the board
/Git_pad/Type_C_VCC: C3.1, C4.1, J3.3, U2.9 (V_{DD}), U2.15 (A0), U2.16 (A1), U2.18 (~RESET); also elsewhere on the board
/Numpad/Numpad_COL_0: MX63.1 (2_2), MX68.1 (2_2), MX73.1 (2_2), MX78.1 (2_2), U2.21 (GPA0)
/Numpad/Numpad_COL_1: MX62.1 (2_2), MX67.1 (2_2), MX72.1 (2_2), MX77.1 (2_2), U2.22 (GPA1)
/Numpad/Numpad_COL_2: MX61.1 (2_2), MX66.1 (2_2), MX71.1 (2_2), MX76.1 (2_2), MX113.1 (2_2), U2.23 (GPA2)
/Numpad/Numpad_COL_3: MX60.1 (2_2), MX65.1 (2_2), MX70.1 (2_2), MX75.1 (2_2), MX80.1 (2_2), U2.24 (GPA3)
/Numpad/Numpad_COL_4: MX59.1 (2_2), MX64.1 (2_2), MX69.1 (2_2), MX74.1 (2_2), MX79.1 (2_2), U2.25 (GPA4)
/Numpad/Numpad_ROW_0: D59.1 (K), D60.1 (K), D61.1 (K), D62.1 (K), D63.1 (K), U2.1 (GPB0)
/Numpad/Numpad_ROW_1: D64.1 (K), D65.1 (K), D66.1 (K), D67.1 (K), D68.1 (K), U2.2 (GPB1)
/Numpad/Numpad_ROW_2: D69.1 (K), D70.1 (K), D71.1 (K), D72.1 (K), D73.1 (K), U2.3 (GPB2)
/Numpad/Numpad_ROW_3: D74.1 (K), D75.1 (K), D76.1 (K), D77.1 (K), D78.1 (K), U2.4 (GPB3)
/Numpad/Numpad_ROW_4: D79.1 (K), D80.1 (K), D113.1 (K), U2.5 (GPB4)
unnamed: D59.2 (A), MX59.2 (1_1)
unnamed: D60.2 (A), MX60.2 (1_1)
unnamed: D61.2 (A), MX61.2 (1_1)
unnamed: D62.2 (A), MX62.2 (1_1)
unnamed: D63.2 (A), MX63.2 (1_1)
unnamed: D64.2 (A), MX64.2 (1_1)
unnamed: D65.2 (A), MX65.2 (1_1)
unnamed: D66.2 (A), MX66.2 (1_1)
unnamed: D67.2 (A), MX67.2 (1_1)
unnamed: D68.2 (A), MX68.2 (1_1)
unnamed: D69.2 (A), MX69.2 (1_1)
unnamed: D70.2 (A), MX70.2 (1_1)
unnamed: D71.2 (A), MX71.2 (1_1)
unnamed: D72.2 (A), MX72.2 (1_1)
unnamed: D73.2 (A), MX73.2 (1_1)
unnamed: D74.2 (A), MX74.2 (1_1)
unnamed: D75.2 (A), MX75.2 (1_1)
unnamed: D76.2 (A), MX76.2 (1_1)
unnamed: D77.2 (A), MX77.2 (1_1)
unnamed: D78.2 (A), MX78.2 (1_1)
unnamed: D79.2 (A), MX79.2 (1_1)
unnamed: D80.2 (A), MX80.2 (1_1)
unnamed: D113.2 (A), MX113.2 (1_1)
unnamed: R8.2, U2.12 (SCK)
unnamed: R7.2, U2.13 (SDA)

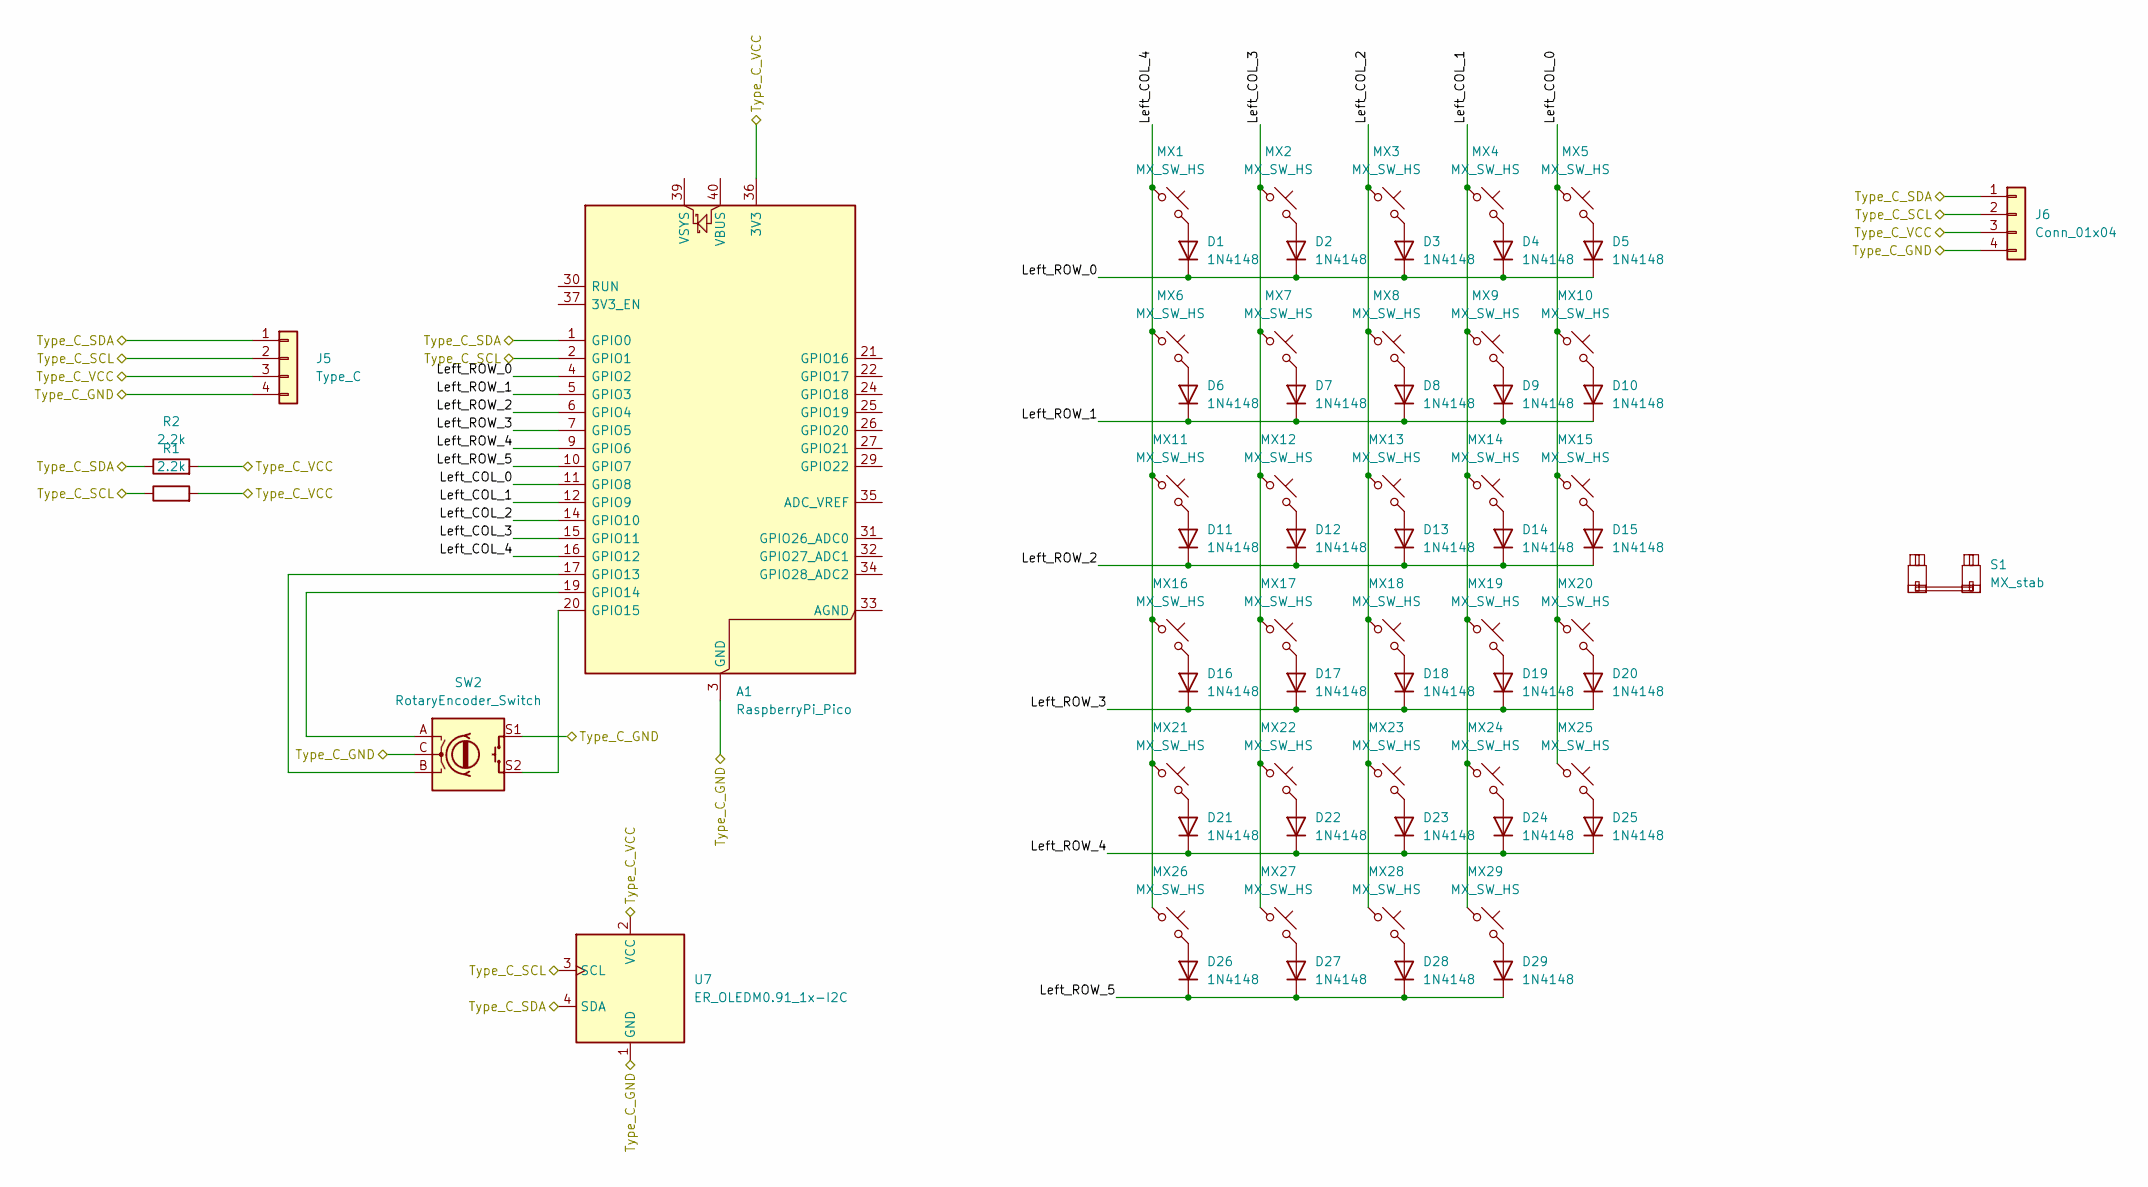
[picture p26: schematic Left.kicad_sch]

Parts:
A1: RaspberryPi_Pico; RaspberryPi_Pico_Common_Unspecified
D1, D2, D3, D4, D5, D6, D7, D8, D9, D10, D11, D12, D13, D14, D15, D16, D17, D18, D19, D20, D21, D22, D23, D24, D25, D26, D27, D28, D29: 1N4148; D_DO-35_SOD27_P7.62mm_Horizontal
J5: Type_C; USB_C_Receptacle_HRO_TYPE-C-31-M-12_4Pin_Fixed
J6: Conn_01x04; PogoMag_1x04_P2.54mm_RightAngle
MX1, MX2, MX3, MX4, MX5, MX6, MX7, MX8, MX9, MX10, MX11, MX12, MX13, MX14, MX15, MX16, MX17, MX18, MX19, MX20, MX21, MX22, MX23, MX24, MX25, MX26, MX27, MX28, MX29: MX_SW_HS; SW_MX_HS_CPG151101S11_1u_PinSwap
R1, R2: 2.2k; R_0603_1608Metric
S1: MX_stab; STAB_MX_P_2u
SW2: RotaryEncoder_Switch; ROT_Alps_EC11E-Switch
U7: ER_OLEDM0.91_1x-I2C

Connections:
/Git_pad/Type_C_GND: A1.3 (GND), A1.8 (GND), A1.13 (GND), A1.18 (GND), A1.23 (GND), A1.28 (GND), A1.38 (GND), J5.4, J6.4, SW2.C, SW2.S1, U7.1 (GND); also elsewhere on the board
/Git_pad/Type_C_SCL: A1.2 (GPIO1), J5.2, J6.2, R1.1, U7.3 (SCL); also elsewhere on the board
/Git_pad/Type_C_SDA: A1.1 (GPIO0), J5.1, J6.1, R2.1, U7.4 (SDA); also elsewhere on the board
/Git_pad/Type_C_VCC: A1.36 (3V3), J5.3, J6.3, R1.2, R2.2, U7.2 (VCC); also elsewhere on the board
/Left/Left_COL_0: A1.11 (GPIO8), MX5.1 (2_2), MX10.1 (2_2), MX15.1 (2_2), MX20.1 (2_2), MX25.1 (2_2)
/Left/Left_COL_1: A1.12 (GPIO9), MX4.1 (2_2), MX9.1 (2_2), MX14.1 (2_2), MX19.1 (2_2), MX24.1 (2_2), MX29.1 (2_2)
/Left/Left_COL_2: A1.14 (GPIO10), MX3.1 (2_2), MX8.1 (2_2), MX13.1 (2_2), MX18.1 (2_2), MX23.1 (2_2), MX28.1 (2_2)
/Left/Left_COL_3: A1.15 (GPIO11), MX2.1 (2_2), MX7.1 (2_2), MX12.1 (2_2), MX17.1 (2_2), MX22.1 (2_2), MX27.1 (2_2)
/Left/Left_COL_4: A1.16 (GPIO12), MX1.1 (2_2), MX6.1 (2_2), MX11.1 (2_2), MX16.1 (2_2), MX21.1 (2_2), MX26.1 (2_2)
/Left/Left_ROW_0: A1.4 (GPIO2), D1.1 (K), D2.1 (K), D3.1 (K), D4.1 (K), D5.1 (K)
/Left/Left_ROW_1: A1.5 (GPIO3), D6.1 (K), D7.1 (K), D8.1 (K), D9.1 (K), D10.1 (K)
/Left/Left_ROW_2: A1.6 (GPIO4), D11.1 (K), D12.1 (K), D13.1 (K), D14.1 (K), D15.1 (K)
/Left/Left_ROW_3: A1.7 (GPIO5), D16.1 (K), D17.1 (K), D18.1 (K), D19.1 (K), D20.1 (K)
/Left/Left_ROW_4: A1.9 (GPIO6), D21.1 (K), D22.1 (K), D23.1 (K), D24.1 (K), D25.1 (K)
/Left/Left_ROW_5: A1.10 (GPIO7), D26.1 (K), D27.1 (K), D28.1 (K), D29.1 (K)
unnamed: A1.17 (GPIO13), SW2.B
unnamed: A1.19 (GPIO14), SW2.A
unnamed: A1.20 (GPIO15), SW2.S2
unnamed: D1.2 (A), MX1.2 (1_1)
unnamed: D2.2 (A), MX2.2 (1_1)
unnamed: D3.2 (A), MX3.2 (1_1)
unnamed: D4.2 (A), MX4.2 (1_1)
unnamed: D5.2 (A), MX5.2 (1_1)
unnamed: D6.2 (A), MX6.2 (1_1)
unnamed: D7.2 (A), MX7.2 (1_1)
unnamed: D8.2 (A), MX8.2 (1_1)
unnamed: D9.2 (A), MX9.2 (1_1)
unnamed: D10.2 (A), MX10.2 (1_1)
unnamed: D11.2 (A), MX11.2 (1_1)
unnamed: D12.2 (A), MX12.2 (1_1)
unnamed: D13.2 (A), MX13.2 (1_1)
unnamed: D14.2 (A), MX14.2 (1_1)
unnamed: D15.2 (A), MX15.2 (1_1)
unnamed: D16.2 (A), MX16.2 (1_1)
unnamed: D17.2 (A), MX17.2 (1_1)
unnamed: D18.2 (A), MX18.2 (1_1)
unnamed: D19.2 (A), MX19.2 (1_1)
unnamed: D20.2 (A), MX20.2 (1_1)
unnamed: D21.2 (A), MX21.2 (1_1)
unnamed: D22.2 (A), MX22.2 (1_1)
unnamed: D23.2 (A), MX23.2 (1_1)
unnamed: D24.2 (A), MX24.2 (1_1)
unnamed: D25.2 (A), MX25.2 (1_1)
unnamed: D26.2 (A), MX26.2 (1_1)
unnamed: D27.2 (A), MX27.2 (1_1)
unnamed: D28.2 (A), MX28.2 (1_1)
unnamed: D29.2 (A), MX29.2 (1_1)

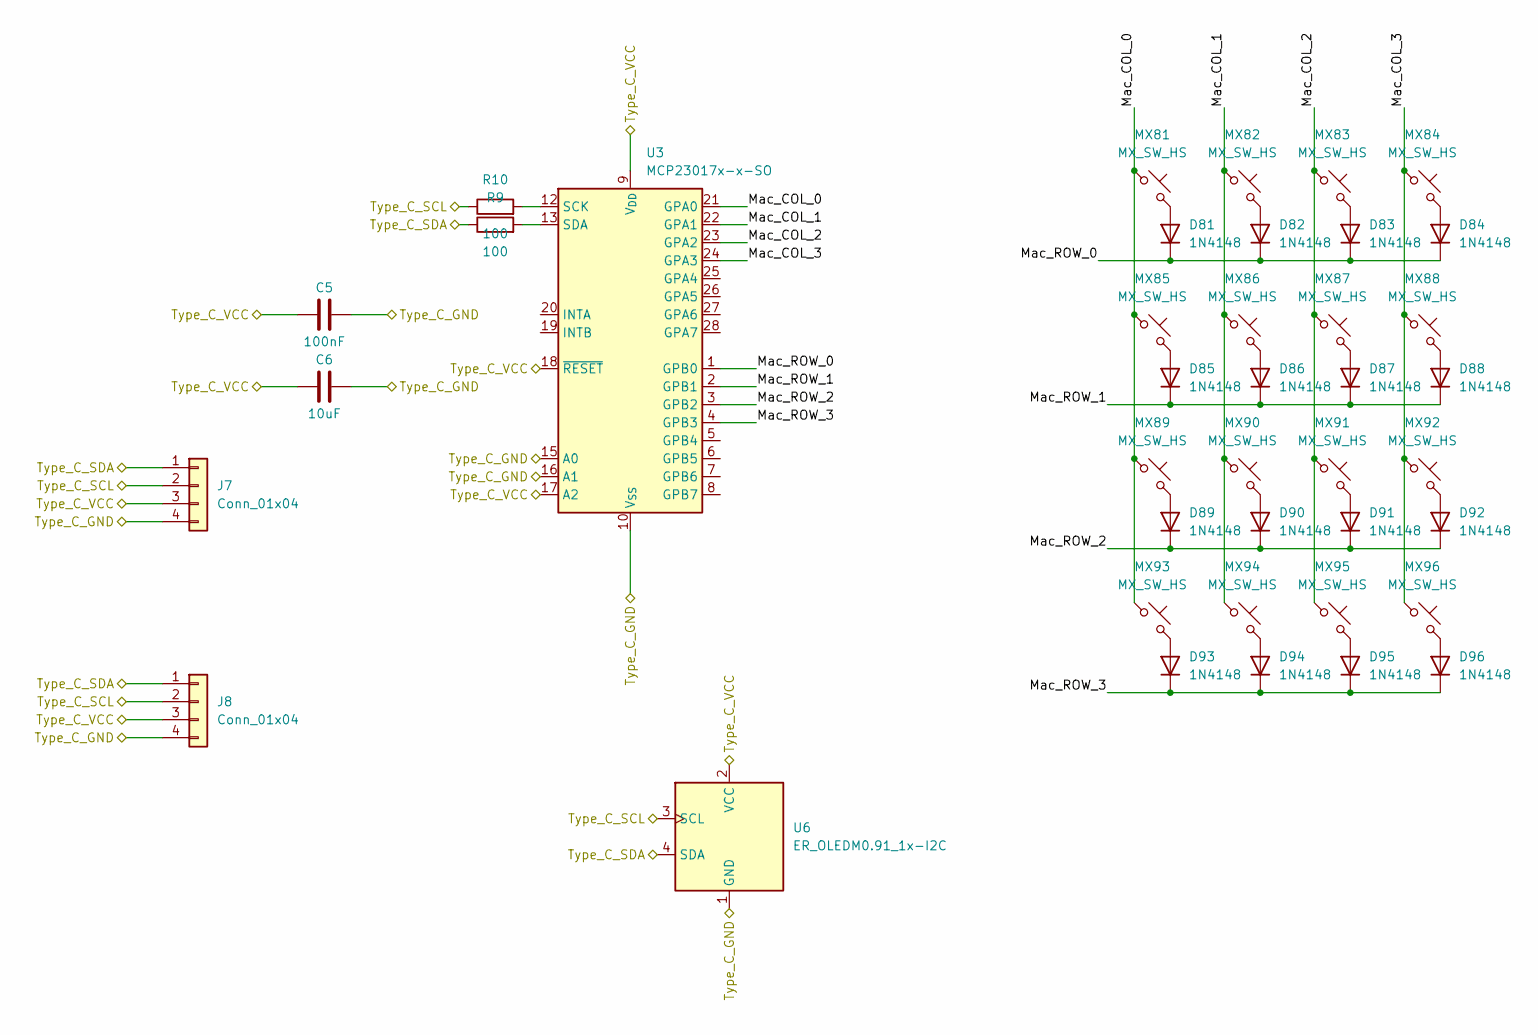
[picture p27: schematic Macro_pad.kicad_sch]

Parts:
C5: 100nF; C_0603_1608Metric
C6: 10uF; C_0805_2012Metric
D81, D82, D83, D84, D85, D86, D87, D88, D89, D90, D91, D92, D93, D94, D95, D96: 1N4148; D_DO-35_SOD27_P7.62mm_Horizontal
J7, J8: Conn_01x04; PogoMag_1x04_P2.54mm_RightAngle
MX81, MX82, MX83, MX84, MX85, MX86, MX87, MX88, MX89, MX90, MX91, MX92, MX93, MX94, MX95, MX96: MX_SW_HS; SW_MX_HS_CPG151101S11_1u_PinSwap
R9, R10: 100; R_0603_1608Metric
U3: MCP23017x-x-SO; SOIC-28W_7.5x17.9mm_P1.27mm
U6: ER_OLEDM0.91_1x-I2C

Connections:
/Git_pad/Type_C_GND: C5.2, C6.2, J7.4, J8.4, U3.10 (V_{SS}), U3.15 (A0), U3.16 (A1), U6.1 (GND); also elsewhere on the board
/Git_pad/Type_C_SCL: J7.2, J8.2, R10.1, U6.3 (SCL); also elsewhere on the board
/Git_pad/Type_C_SDA: J7.1, J8.1, R9.1, U6.4 (SDA); also elsewhere on the board
/Git_pad/Type_C_VCC: C5.1, C6.1, J7.3, J8.3, U3.9 (V_{DD}), U3.17 (A2), U3.18 (~RESET), U6.2 (VCC); also elsewhere on the board
/Macro_pad/Mac_COL_0: MX81.1 (2_2), MX85.1 (2_2), MX89.1 (2_2), MX93.1 (2_2), U3.21 (GPA0)
/Macro_pad/Mac_COL_1: MX82.1 (2_2), MX86.1 (2_2), MX90.1 (2_2), MX94.1 (2_2), U3.22 (GPA1)
/Macro_pad/Mac_COL_2: MX83.1 (2_2), MX87.1 (2_2), MX91.1 (2_2), MX95.1 (2_2), U3.23 (GPA2)
/Macro_pad/Mac_COL_3: MX84.1 (2_2), MX88.1 (2_2), MX92.1 (2_2), MX96.1 (2_2), U3.24 (GPA3)
/Macro_pad/Mac_ROW_0: D81.1 (K), D82.1 (K), D83.1 (K), D84.1 (K), U3.1 (GPB0)
/Macro_pad/Mac_ROW_1: D85.1 (K), D86.1 (K), D87.1 (K), D88.1 (K), U3.2 (GPB1)
/Macro_pad/Mac_ROW_2: D89.1 (K), D90.1 (K), D91.1 (K), D92.1 (K), U3.3 (GPB2)
/Macro_pad/Mac_ROW_3: D93.1 (K), D94.1 (K), D95.1 (K), D96.1 (K), U3.4 (GPB3)
unnamed: D81.2 (A), MX81.2 (1_1)
unnamed: D82.2 (A), MX82.2 (1_1)
unnamed: D83.2 (A), MX83.2 (1_1)
unnamed: D84.2 (A), MX84.2 (1_1)
unnamed: D85.2 (A), MX85.2 (1_1)
unnamed: D86.2 (A), MX86.2 (1_1)
unnamed: D87.2 (A), MX87.2 (1_1)
unnamed: D88.2 (A), MX88.2 (1_1)
unnamed: D89.2 (A), MX89.2 (1_1)
unnamed: D90.2 (A), MX90.2 (1_1)
unnamed: D91.2 (A), MX91.2 (1_1)
unnamed: D92.2 (A), MX92.2 (1_1)
unnamed: D93.2 (A), MX93.2 (1_1)
unnamed: D94.2 (A), MX94.2 (1_1)
unnamed: D95.2 (A), MX95.2 (1_1)
unnamed: D96.2 (A), MX96.2 (1_1)
unnamed: R10.2, U3.12 (SCK)
unnamed: R9.2, U3.13 (SDA)

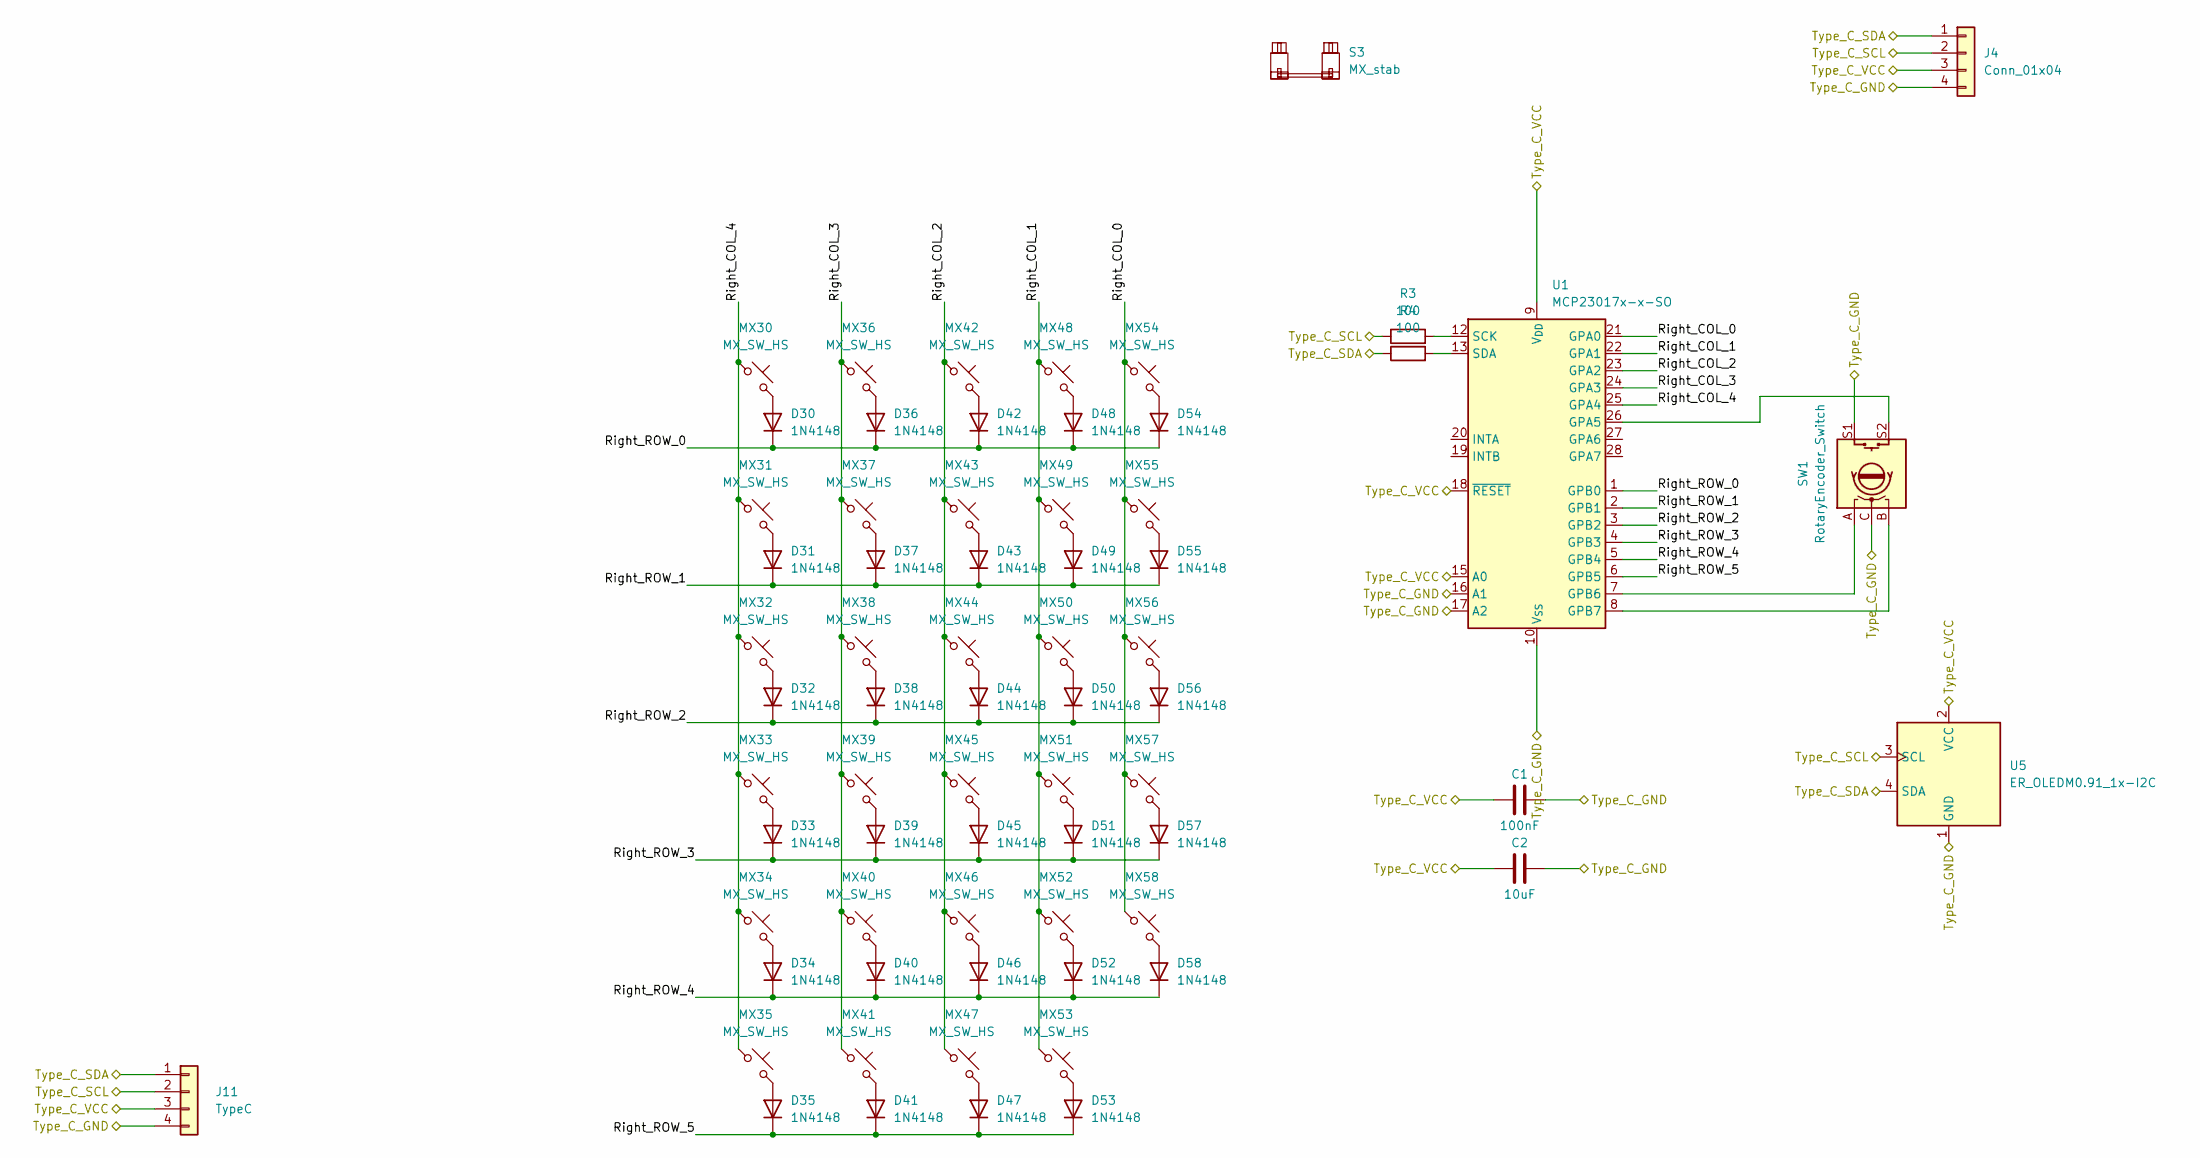
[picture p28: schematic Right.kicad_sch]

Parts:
C1: 100nF; C_0603_1608Metric
C2: 10uF; C_0805_2012Metric
D30, D31, D32, D33, D34, D35, D36, D37, D38, D39, D40, D41, D42, D43, D44, D45, D46, D47, D48, D49, D50, D51, D52, D53, D54, D55, D56, D57, D58: 1N4148; D_DO-35_SOD27_P7.62mm_Horizontal
J4: Conn_01x04; PogoMag_1x04_P2.54mm_RightAngle
J11: TypeC; USB_C_Receptacle_HRO_TYPE-C-31-M-12_4Pin_Fixed
MX30, MX31, MX32, MX33, MX34, MX35, MX36, MX37, MX38, MX39, MX40, MX41, MX42, MX43, MX44, MX45, MX46, MX47, MX48, MX49, MX50, MX51, MX52, MX53, MX54, MX55, MX56, MX57, MX58: MX_SW_HS; SW_MX_HS_CPG151101S11_1u_PinSwap
R3, R4: 100; R_0603_1608Metric
S3: MX_stab; STAB_MX_P_2u
SW1: RotaryEncoder_Switch; ROT_Alps_EC11E-Switch
U1: MCP23017x-x-SO; SOIC-28W_7.5x17.9mm_P1.27mm
U5: ER_OLEDM0.91_1x-I2C

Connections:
/Git_pad/Type_C_GND: C1.2, C2.2, J4.4, J11.4, SW1.C, SW1.S1, U1.10 (V_{SS}), U1.16 (A1), U1.17 (A2), U5.1 (GND); also elsewhere on the board
/Git_pad/Type_C_SCL: J4.2, J11.2, R3.1, U5.3 (SCL); also elsewhere on the board
/Git_pad/Type_C_SDA: J4.1, J11.1, R4.1, U5.4 (SDA); also elsewhere on the board
/Git_pad/Type_C_VCC: C1.1, C2.1, J4.3, J11.3, U1.9 (V_{DD}), U1.15 (A0), U1.18 (~RESET), U5.2 (VCC); also elsewhere on the board
/Right/Right_COL_0: MX54.1 (2_2), MX55.1 (2_2), MX56.1 (2_2), MX57.1 (2_2), MX58.1 (2_2), U1.21 (GPA0)
/Right/Right_COL_1: MX48.1 (2_2), MX49.1 (2_2), MX50.1 (2_2), MX51.1 (2_2), MX52.1 (2_2), MX53.1 (2_2), U1.22 (GPA1)
/Right/Right_COL_2: MX42.1 (2_2), MX43.1 (2_2), MX44.1 (2_2), MX45.1 (2_2), MX46.1 (2_2), MX47.1 (2_2), U1.23 (GPA2)
/Right/Right_COL_3: MX36.1 (2_2), MX37.1 (2_2), MX38.1 (2_2), MX39.1 (2_2), MX40.1 (2_2), MX41.1 (2_2), U1.24 (GPA3)
/Right/Right_COL_4: MX30.1 (2_2), MX31.1 (2_2), MX32.1 (2_2), MX33.1 (2_2), MX34.1 (2_2), MX35.1 (2_2), U1.25 (GPA4)
/Right/Right_ROW_0: D30.1 (K), D36.1 (K), D42.1 (K), D48.1 (K), D54.1 (K), U1.1 (GPB0)
/Right/Right_ROW_1: D31.1 (K), D37.1 (K), D43.1 (K), D49.1 (K), D55.1 (K), U1.2 (GPB1)
/Right/Right_ROW_2: D32.1 (K), D38.1 (K), D44.1 (K), D50.1 (K), D56.1 (K), U1.3 (GPB2)
/Right/Right_ROW_3: D33.1 (K), D39.1 (K), D45.1 (K), D51.1 (K), D57.1 (K), U1.4 (GPB3)
/Right/Right_ROW_4: D34.1 (K), D40.1 (K), D46.1 (K), D52.1 (K), D58.1 (K), U1.5 (GPB4)
/Right/Right_ROW_5: D35.1 (K), D41.1 (K), D47.1 (K), D53.1 (K), U1.6 (GPB5)
unnamed: D30.2 (A), MX30.2 (1_1)
unnamed: D31.2 (A), MX31.2 (1_1)
unnamed: D32.2 (A), MX32.2 (1_1)
unnamed: D33.2 (A), MX33.2 (1_1)
unnamed: D34.2 (A), MX34.2 (1_1)
unnamed: D35.2 (A), MX35.2 (1_1)
unnamed: D36.2 (A), MX36.2 (1_1)
unnamed: D37.2 (A), MX37.2 (1_1)
unnamed: D38.2 (A), MX38.2 (1_1)
unnamed: D39.2 (A), MX39.2 (1_1)
unnamed: D40.2 (A), MX40.2 (1_1)
unnamed: D41.2 (A), MX41.2 (1_1)
unnamed: D42.2 (A), MX42.2 (1_1)
unnamed: D43.2 (A), MX43.2 (1_1)
unnamed: D44.2 (A), MX44.2 (1_1)
unnamed: D45.2 (A), MX45.2 (1_1)
unnamed: D46.2 (A), MX46.2 (1_1)
unnamed: D47.2 (A), MX47.2 (1_1)
unnamed: D48.2 (A), MX48.2 (1_1)
unnamed: D49.2 (A), MX49.2 (1_1)
unnamed: D50.2 (A), MX50.2 (1_1)
unnamed: D51.2 (A), MX51.2 (1_1)
unnamed: D52.2 (A), MX52.2 (1_1)
unnamed: D53.2 (A), MX53.2 (1_1)
unnamed: D54.2 (A), MX54.2 (1_1)
unnamed: D55.2 (A), MX55.2 (1_1)
unnamed: D56.2 (A), MX56.2 (1_1)
unnamed: D57.2 (A), MX57.2 (1_1)
unnamed: D58.2 (A), MX58.2 (1_1)
unnamed: SW1.S2, U1.26 (GPA5)
unnamed: SW1.A, U1.7 (GPB6)
unnamed: SW1.B, U1.8 (GPB7)
unnamed: R3.2, U1.12 (SCK)
unnamed: R4.2, U1.13 (SDA)

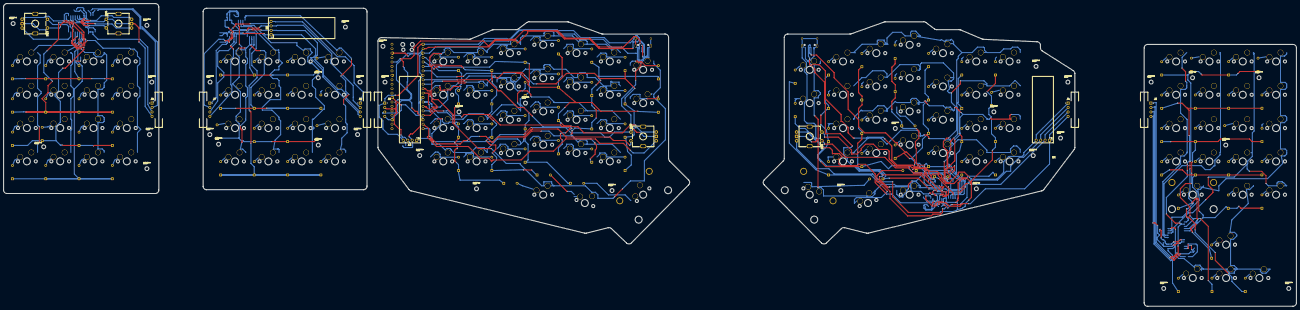
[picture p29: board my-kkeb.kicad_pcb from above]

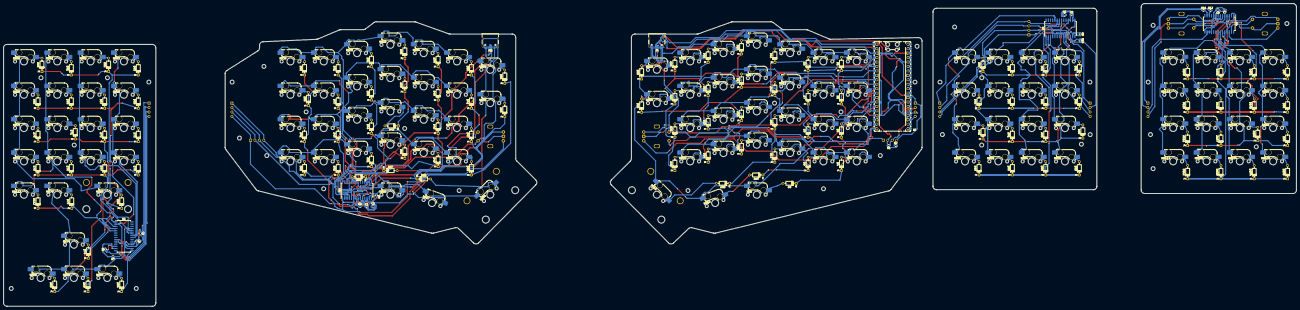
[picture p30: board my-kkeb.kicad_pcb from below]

Board: 2 copper layers, 739.3 x 173.1 mm, 267 parts (251 on the bottom side), 185 nets.

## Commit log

2026-08-19 I updated the readme with everything I have done until today. There is also all the wiring on the kicad folder
    [Git_pad.kicad_sch, Left.kicad_sch, Macro_pad.kicad_sch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]
2026-09-25 This is basically the finished thing. The only thing left if the BOM
    [Case_Git_pad.step, Case_Left.step, Case_Macro_pad.step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]
2026-09-26 I added the BOM
    [Plate_Left.step, bom.csv, my-kkeb.csv]
2026-09-29 I added the finished BOM
    [bom.csv]
